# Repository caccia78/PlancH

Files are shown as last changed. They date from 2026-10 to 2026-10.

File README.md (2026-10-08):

# PlancH

**A desk button panel for Home Assistant.** Ten tactile buttons, a small OLED display, a touch
area and thirteen addressable RGB LEDs on a black PCB that sits on your desk, either on its own
rubber feet or on a 3D-printed stand. Powered by a Waveshare ESP32-S3-Zero running
[ESPHome](https://esphome.io), with native Home Assistant integration.

**📖 Documentation: [caccia78.github.io/PlancH](https://caccia78.github.io/PlancH/)**

https://github.com/user-attachments/assets/e7710835-a2c8-45fb-a4f4-b32c819555f0

*The video is also in [`media/`](media/) (MP4 and WebM).*

> **Status: Rev. 1, prototypes on order.** The design is complete and passes ERC/DRC, but the
> first boards have not been assembled and tested yet. Build one if you like to tinker, and
> expect changes.

## Features

- **10 tactile buttons**: a directional pad (up, down, left, right, OK), Back, and four scene buttons.
- **0.96" OLED display** (SSD1306, 128 × 64, white) for menus and feedback.
- **Capacitive touch area** on the top "ear" to wake the display.
- **13 addressable RGB LEDs** (SK6812): 3 status LEDs, 4 scene LEDs shining through milled
  windows in the PCB, and 6 backlight LEDs that light up the desk underneath.
- **Waveshare ESP32-S3-Zero** module, powered and programmed over USB-C.
- **Hand-solderable**: no parts with contacts under the body, passives 0805 or larger.
- **ESPHome firmware** with native Home Assistant API.
- **Accessories**: a 3D-printed desk stand, with more to come.

| Front | Back |
| --- | --- |
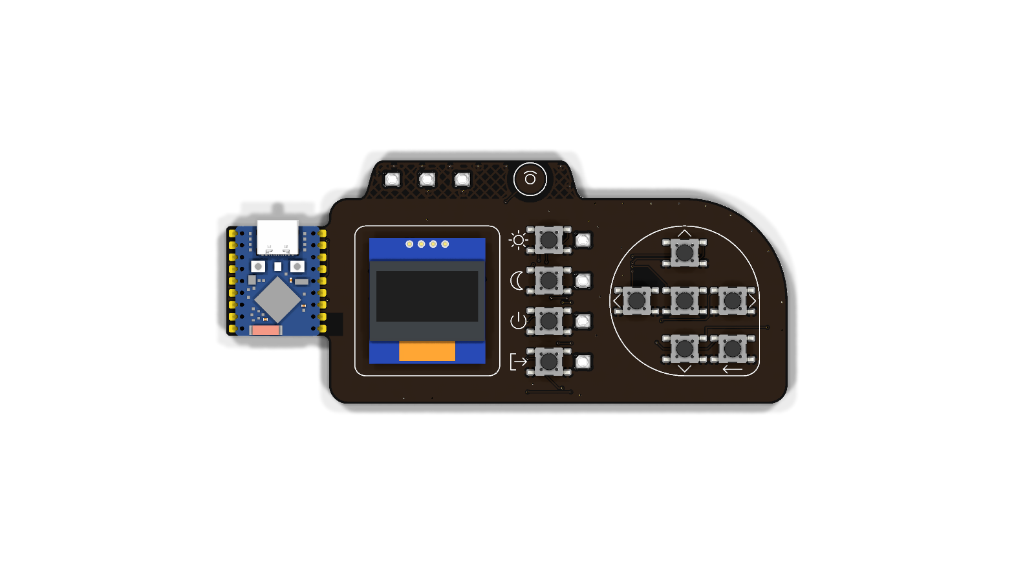
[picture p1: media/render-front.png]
Front render
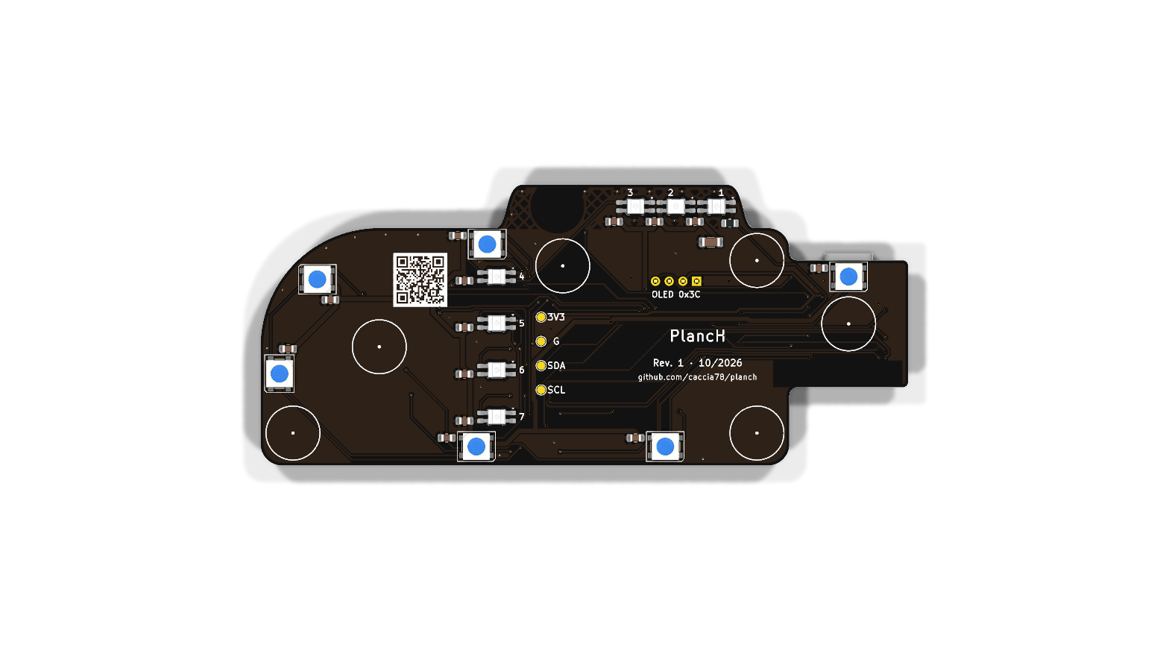
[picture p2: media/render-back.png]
Back render
|  |  |

## Build your own

1. **Order the PCB.** Upload `production/gerber/` (or the Gerber ZIP attached to the
   [latest release](../../releases/latest)) to JLCPCB, PCBWay or any other maker.
   Reference settings: 2 layers, 2.0 mm FR4 (1.6 mm works too), matte black solder mask,
   white silkscreen, ENIG finish.
2. **Get the components.** The bill of materials is in
   [`production/planch-bom.csv`](production/planch-bom.csv), with manufacturer part numbers.
3. **Solder.** Open [`production/planch-ibom.html`](production/planch-ibom.html) in a browser:
   the interactive BOM highlights every part on the board. Suggested order: passives and LEDs
   on the back, buttons, ESP32 module, OLED last.
4. **Flash the firmware.** Run `esphome run firmware/planch.yaml` and set the Wi-Fi after
   flashing. Then install the Home Assistant package `homeassistant/planch.yaml` and put the
   label **PlancH** on the devices to control: the panel finds them by itself, by room.
5. **Print a stand** (optional): the [desk stand](mechanical/desk-stand/README.md) or the
   magnetic [wall mount](mechanical/wall-mount/README.md), with ready-to-print 3MF and STL files.

The [project website](https://caccia78.github.io/PlancH/) has the full documentation:
[components with shop links](https://caccia78.github.io/PlancH/build/components/),
[PCB ordering](https://caccia78.github.io/PlancH/build/ordering/), a step-by-step
[assembly guide](https://caccia78.github.io/PlancH/build/assembly/),
[firmware](https://caccia78.github.io/PlancH/firmware/) and
[Home Assistant](https://caccia78.github.io/PlancH/home-assistant/) setup.

## Repository layout

```
hardware/      KiCad 10 project: schematic, PCB, custom symbols, footprints and 3D models
production/    Gerber and drill files, BOM, pick-and-place, interactive BOM, schematic PDF, STEP
mechanical/    3D-printable accessories (build123d sources, STL, 3MF, STEP)
firmware/      ESPHome: planch.yaml (board), planch-bringup.yaml (assembly test), planch-test.yaml (test bench)
homeassistant/ Home Assistant package (menu from labels and areas) and test bench dashboard
media/         renders and video
```

## License

PlancH is open source hardware.

- **Hardware** (KiCad sources, production files, 3D-printed accessories):
  [CERN-OHL-S v2](LICENSES/CERN-OHL-S-2.0.txt)
- **Firmware and scripts**: [MIT](LICENSES/MIT.txt)
- **Documentation, renders and video**: [CC BY-SA 4.0](LICENSES/CC-BY-SA-4.0.txt)

See [LICENSE.md](LICENSE.md) for details. The source location printed on the back of the board
is `github.com/caccia78/planch`.

© 2026 Vincenzo Cacciatore

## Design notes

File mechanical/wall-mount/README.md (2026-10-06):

# Wall mount

Hangs PlancH on a wall or any flat vertical surface. A ring bracket is glued behind the board in
place of the rubber feet, a base is stuck to the wall with removable adhesive strips, and six
5 × 3 mm magnets plus two centring cones hold them together. Both parts follow the board outline
9.5 mm in, so the backlight LEDs shine on the wall around them.

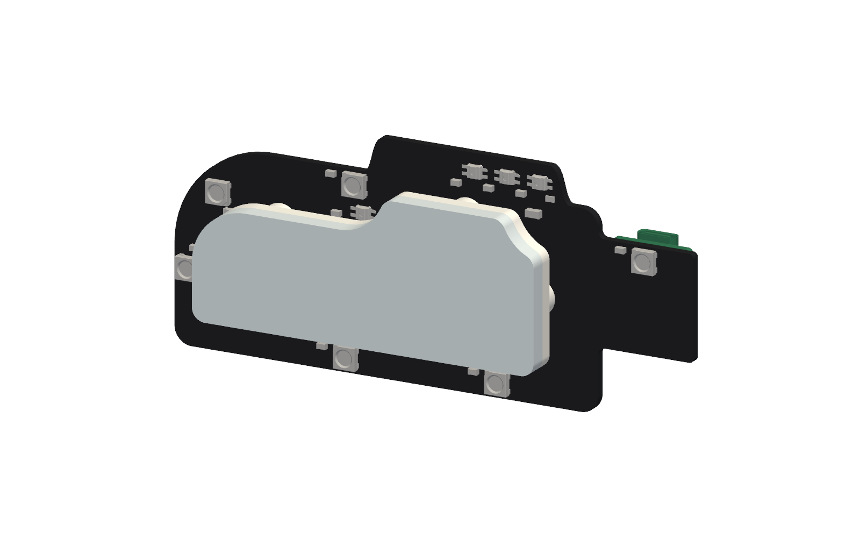
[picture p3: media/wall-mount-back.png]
Wall mount behind the board


Full instructions (parts list, magnet polarity, assembly) on the
[project website](https://caccia78.github.io/PlancH/accessories/wall-mount/).

## Files

| File | Use |
| --- | --- |
| `planch-wall-bracket.3mf`, `planch-wall-base.3mf` | Ready for Bambu Studio / PrusaSlicer, already oriented |
| `planch-wall-bracket.stl`, `planch-wall-base.stl` | Any slicer |
| `planch-wall-bracket.step`, `planch-wall-base.step` | CAD |
| `parete.py` | Parametric source ([build123d](https://github.com/gumyr/build123d) and shapely) |

## Printing

- PLA, both parts with the wall side on the bed, no supports.
- White or light PLA for the base: it sits in the backlight.

## Changing it

```bash
uv run --no-project --python 3.12 --with build123d --with shapely python parete.py \
    --board ../../production/planch.step --out .
```

The script writes `parete-staffa` (bracket) and `parete-base` (base) files ("parete" is Italian
for "wall", "staffa" for "bracket") and checks that the pads avoid the components on the back
and that no part covers the backlight LEDs.

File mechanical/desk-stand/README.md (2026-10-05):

# Desk stand

A 3D-printed stand that holds PlancH at 20° on the desk. The board keeps its rubber feet and
simply drops into a frame that follows its outline; slots in the frame let the backlight LEDs
shine out.

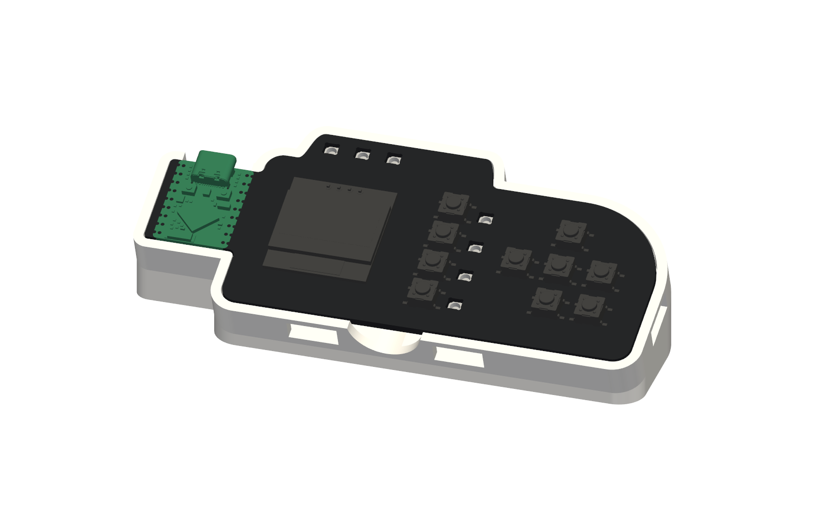
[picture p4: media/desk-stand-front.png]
Desk stand with PlancH


## Files

| File | Use |
| --- | --- |
| `planch-desk-stand.3mf` | Ready for Bambu Studio / PrusaSlicer, already oriented |
| `planch-desk-stand.stl` | Any slicer |
| `planch-desk-stand.step` | CAD |
| `leggio.py` | Parametric source ([build123d](https://github.com/gumyr/build123d)) |

## Printing

- PLA, printed on its base, no supports. Tested settings: Bambu Lab A1, 0.2 mm layers, 15% infill.
- White or light PLA works best: the inside of the frame reflects the backlight through the slots.
- Four 10 mm rubber bumpers go in the recesses underneath.

## Fit

The frame is sized for the board with its 5 mm feet and a 0.3 mm gap on every side. If your
printer runs tight or your feet are taller, regenerate the model:

```bash
uv run --no-project --python 3.12 --with build123d python leggio.py \
    --board ../../production/planch.step --out . --feet 6 --pcb 1.6
```

`--pcb` is the board thickness (2.0 mm by default, 1.6 mm for thinner boards), `--feet` the
height of the rubber feet. The script writes `leggio.*` files ("leggio" is Italian for
"stand").

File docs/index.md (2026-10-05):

---
hide:
  - navigation
  - toc
---

# PlancH

**A desk button panel for Home Assistant.** Ten tactile buttons, a small OLED display, a touch
area and thirteen addressable RGB LEDs on a black PCB that sits on your desk, on its own rubber
feet or on a 3D-printed stand. Powered by a Waveshare ESP32-S3-Zero running
[ESPHome](https://esphome.io), with native Home Assistant integration.

<video class="hero-video" controls muted playsinline preload="metadata" poster="media/planch-video-poster.png">
  <source src="media/planch-video.webm" type="video/webm">
  <source src="media/planch-video.mp4" type="video/mp4">
</video>

!!! warning "Rev. 1: prototypes on order"
    The design is complete and passes ERC and DRC, but the first boards have not been
    assembled and tested yet. Build one if you like to tinker, and expect changes.

<div class="grid cards" markdown>

-   :material-gesture-tap-button: **10 buttons**

    ---

    Directional pad with OK, Back, and four scene buttons for your favourite routines.

-   :material-monitor: **OLED display**

    ---

    0.96" SSD1306, 128 × 64 white pixels for menus and feedback, woken by a touch on the top
    "ear".

-   :material-led-strip-variant: **13 RGB LEDs**

    ---

    3 status LEDs, 4 scene LEDs shining through windows milled in the PCB, and 6 backlight
    LEDs that light up the desk.

-   :material-home-assistant: **ESPHome inside**

    ---

    Waveshare ESP32-S3-Zero over USB-C, native Home Assistant API, no cloud.

-   :material-soldering-iron: **Hand-solderable**

    ---

    No parts with contacts under the body, passives 0805 or larger. About 2–3 hours for the
    first board.

-   :material-printer-3d-nozzle: **Accessories**

    ---

    A 3D-printed desk stand, with more mounts to come.

</div>

| Front | Back |
| --- | --- |
| Front of the board | Back of the board |

## Build your own

<div class="grid cards" markdown>

-   :material-format-list-checks: **[Components](build/components.md)**

    Bill of materials with shop links.

-   :material-chip: **[Ordering the PCB](build/ordering.md)**

    Gerber files and fab settings.

-   :material-soldering-iron: **[Assembly](build/assembly.md)**

    Step-by-step soldering guide with a test at every stage.

-   :material-download: **[Firmware](firmware/index.md)**

    Flash ESPHome and connect to Home Assistant.

</div>

All design files (KiCad sources, Gerbers, 3D models, firmware) are in the
[GitHub repository](https://github.com/caccia78/PlancH). PlancH is
[open source hardware](about/license.md).

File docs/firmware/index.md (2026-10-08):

# Firmware

PlancH runs [ESPHome](https://esphome.io). The devices to control are not written in the
firmware: you choose them in Home Assistant with a label, and PlancH builds its menu by itself,
by room and by type. See [Home Assistant](../home-assistant/index.md) for the setup.

| File | Use |
| --- | --- |
| [`firmware/planch.yaml`](https://github.com/caccia78/PlancH/blob/main/firmware/planch.yaml) | **The firmware**: menu on the display, keys, LEDs |
| [`firmware/planch/`](https://github.com/caccia78/PlancH/tree/main/firmware/planch) | Shared logic (`core.yaml`, `menu.h`): keep it next to `planch.yaml` |
| [`firmware/planch-bringup.yaml`](https://github.com/caccia78/PlancH/blob/main/firmware/planch-bringup.yaml) | Assembly test: buttons and LED groups on a web page, see the [assembly guide](../build/assembly.md) |
| [`firmware/planch-test.yaml`](https://github.com/caccia78/PlancH/blob/main/firmware/planch-test.yaml) | Test bench on any ESP32 board, without the PlancH hardware: see [Try it without the hardware](test-bench.md) |

## Install from the browser

The quickest way, with nothing to install: the firmware is built from this repository and
written by the browser (Chrome or Edge on a computer).

<script type="module" src="https://unpkg.com/esp-web-tools@10.4.0/dist/web/install-button.js?module"></script>

<p>
  <esp-web-install-button manifest="/PlancH/firmware/install/manifest.json">
    <span slot="unsupported">This browser cannot talk to USB devices: open the page in Chrome or Edge on a computer.</span>
    <span slot="not-allowed">The installer needs a secure (https) page.</span>
  </esp-web-install-button>
</p>

1. Connect the board with a USB-C **data** cable and press **Connect** above.
2. Choose the serial port of the board. If it does not appear, hold the **BOOT** button of the
   ESP32-S3-Zero while plugging in the cable, then try again.
3. Choose **Install PlancH**. Erasing the board is fine for a first installation.
4. At the end choose **Configure Wi-Fi**, pick your network and type its password: it stays on
   the board, not in any file.
5. Add the board to Home Assistant as described in [Home Assistant](../home-assistant/index.md).

This button installs PlancH on its ESP32-S3-Zero. To try the menu on a spare ESP32 board before
building PlancH, see [Try it without the hardware](test-bench.md).

## Flash with ESPHome

You need [ESPHome](https://esphome.io/guides/installing_esphome) on your computer
(`pip install esphome`, or `uvx esphome` with [uv](https://docs.astral.sh/uv/)), or the ESPHome
Device Builder add-on in Home Assistant.

1. Download the repository, or just the `firmware/` folder. With the Device Builder, copy
   `planch.yaml` and the `planch/` folder into the `esphome` folder of Home Assistant (next to
   `configuration.yaml`).
2. Connect the board with a USB-C **data** cable.
3. Run:

    ```bash
    esphome run firmware/planch.yaml
    ```

    The first time, choose the USB serial port. If the board is not detected, hold the **BOOT**
    button on the ESP32-S3-Zero while plugging in the cable.

4. **Wi-Fi.** The firmware has no Wi-Fi password in it: set it after flashing.
    - Open [web.esphome.io](https://web.esphome.io) in Chrome or Edge, press **Connect**, pick
      the board and choose **Configure Wi-Fi**; or
    - join the **PlancH** Wi-Fi network that the board opens while it has no network, and pick
      your network on the page that appears (or open `192.168.4.1`).
5. Later updates go over Wi-Fi (OTA): run the same command and pick the network address.

Then add the board to Home Assistant and enable its actions, as described in
[Home Assistant](../home-assistant/index.md).

## Keys and display

The display shows rooms → types in the room (skipped if there is only one) → devices →
the controls of one device.

| Key | In the lists | On a device |
| --- | --- | --- |
| Up, Down | Move | Light: move through its rows, and past the last row on to the next light. Switch, thermostat: previous / next. Cover: open / close |
| OK | Enter | Light, switch, thermostat: on / off. Cover: stop |
| Left, Right | Back / enter | Light: change the selected row. Switch: off / on. Thermostat: −/+ 0.5 °C |
| Back | Go back | Go back to the list |
| Scene 1–4 | Run the scene, script or automation assigned in Home Assistant | Same |
| Touch | Wake the display | Wake the display |

The screen of a light shows only the rows that the light supports:

```
Strip
> Brightness      70%
  Colour          Red
  White         2700K
  Effect       Candle
```

- **Brightness**: ±10% (a light that can only switch on and off has a **State** row instead).
- **Colour**: previous / next colour of the palette defined in the
  [Home Assistant package](../home-assistant/index.md#colours); the row shows the palette colour
  closest to the current one.
- **White**: warmer / cooler in steps of 500 K, within the range of the light.
- **Effect**: previous / next effect of the light (WLED and many others), picked by Home
  Assistant from the light's own list.

The display switches off after 30 seconds without keys; the first key only wakes it up. The
scene keys work with the display off too.

## LEDs

| LED | Meaning |
| --- | --- |
| D1 (ear, left) | Off when everything is fine. Red: no connection to Home Assistant. Amber: menu missing, empty or over the limits. Short red flash: a command failed |
| D2, D3 (ear) | Free: two RGB lights in Home Assistant, **Status LED 2** and **Status LED 3**, for your automations |
| D4–D7 (scene keys) | On with the display, and for 5 seconds after a scene key. Full on the **active scene**, dim on the other assigned keys. After a press: green if Home Assistant confirms, red on error |
| D8–D13 (backlight) | The RGB light **Backlight** in Home Assistant |

LED brightness is limited to 40% in the firmware to keep the USB current low.

## What the firmware exposes

| Entity | Type | Notes |
| --- | --- | --- |
| Up, Down, Left, Right, OK, Back, Scene 1 – Scene 4 | Binary sensor | `on` while pressed: you can use them in automations too |
| Panel | Text | Name of the panel, picks its devices: see [More than one PlancH](../home-assistant/index.md#more-than-one-planch) |
| Touch | Binary sensor | Capacitive area on the ear, calibrate the threshold |
| Status LED 2, Status LED 3 | Light (RGB) | D2 and D3 on the ear |
| Backlight | Light (RGB) | D8–D13, towards the desk (or the wall) |

## Calibrating the touch area

The touch threshold depends on your board and on the stand. With `setup_mode: true` (the
default in `planch.yaml`) the ESPHome log prints the raw touch value:

1. Read the value at rest and with a finger on the ear.
2. Set `threshold` about halfway between the two.
3. Set `setup_mode: false` and flash again.

## Test bench without the hardware

The same menu runs on any ESP32 board with nothing connected, driven from a Home Assistant card
that draws PlancH: see [Try it without the hardware](test-bench.md).

## Pinout

| GPIO | Function | GPIO | Function |
| --- | --- | --- | --- |
| 1 | Up | 9 | Scene 1 |
| 2 | Down | 10 | LED data (via 330 Ω) |
| 3 | Left (strapping pin, input only) | 11 | I²C SDA |
| 4 | Right | 12 | I²C SCL |
| 5 | OK | 13 | Touch |
| 6 | Scene 4 | 44 (RX) | Back |
| 7 | Scene 3 | 43 (TX) | not used (boot log) |
| 8 | Scene 2 | 21 | RGB LED on the module |

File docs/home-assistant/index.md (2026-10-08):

# Home Assistant

PlancH talks to Home Assistant through the native ESPHome API: no MQTT broker, no cloud.
You choose what it controls with **labels**: PlancH finds the devices by itself and groups them
by room (area) and type, so adding a lamp to the panel takes one click and no new firmware.

## 1 · Install the PlancH package

The package
[`homeassistant/planch.yaml`](https://github.com/caccia78/PlancH/blob/main/homeassistant/planch.yaml)
creates the sensor `sensor.planch_menu`, which collects the labelled devices with their state
and sends them to the panel.

1. In the Home Assistant configuration folder (the one with `configuration.yaml`) create a
   folder `packages` and copy `planch.yaml` into it.
2. If `configuration.yaml` does not load packages yet, add at the top level:

    ```yaml
    homeassistant:
      packages: !include_dir_named packages
    ```

3. **Developer tools → YAML → Check configuration**, then restart Home Assistant.
4. In **Developer tools → States** you find `sensor.planch_menu`: its state is the number of
   labelled devices (0 for now).

## 2 · Add the board

1. [Flash the firmware](../firmware/index.md) and let the board join your Wi-Fi.
2. Home Assistant discovers it: open **Settings → Devices & services**, find **PlancH** under
   *Discovered* and click **Configure**. If it is not discovered, click **Add integration →
   ESPHome** and enter the board's IP address (or `planch.local`).
3. On the ESPHome integration, open the **PlancH** device options (**Configure**) and enable
   **Allow the device to perform Home Assistant actions**. Without it the menu shows up but
   the keys do nothing.

## 3 · Choose the devices

Create the label **PlancH** (**Settings → Areas, labels & zones → Labels**) and put it on the
lights, switches (smart plugs), covers and thermostats (climate) you want on the panel.

- Put it on the **entity**, to choose exactly what appears; or on the **device**, to take all
  its lights, switches, covers and thermostats.
- A lamp on a smart plug is often a `switch`: it appears under **Switches**. To have it under
  **Lights**, turn it into a light with the Home Assistant helper *Change device type of a
  switch* and label the new light instead.
- The room is the area of the entity, or of its device. Without an area the device goes under
  **Other**.
- The name shown is the entity name without the room in front ("Living room Lamp" →
  "Lamp"), cut to 16 characters.

The menu updates by itself: states live, and labels or areas within a couple of seconds (the
package includes a small automation, **PlancH: refresh the menu when labels or areas change**,
for that).

!!! warning "Limits"
    A panel shows at most **8 rooms**, **8 devices per room** and **32 devices** in total:
    more would not fit in the ESP32 memory nor on the 0.96" display. Beyond the limits the list
    is cut, the LED D1 turns amber and the room list reads "Rooms (limit!)".

### More than one PlancH

Each panel can show its own devices besides the shared ones:

1. Give the panel a name: on its device page in Home Assistant, under **Configuration**, type
   it in the **Panel** field (for example *Studio*). No new firmware needed.
2. Create the label **PlancH Studio** and put it on the devices for that panel only.

The panel named Studio shows the devices with **PlancH** and with **PlancH Studio**; a device
can have several labels to appear on more than one panel. A panel without a name, or with a
name that has no label, shows the **PlancH** devices. Names are not case sensitive, and up to
6 named panels are supported.

## 4 · Assign the scene keys

Create the labels **PlancH S1**, **PlancH S2**, **PlancH S3** and **PlancH S4** and put each
one on the scene, script or automation for that key (one entity per label): a scene is turned
on, a script is run, an automation is triggered. A key without a label does nothing.

With more panels, **PlancH Studio S1** … **PlancH Studio S4** set the keys of the panel Studio
only, and win over the shared ones.

The LED next to each key shows the **active scene**: the one activated most recently among the
four, also when you activate it from Home Assistant or from an automation (a script also while
it runs). When you press a key, its LED turns green if Home Assistant confirms, red on error.

## Colours

On a colour light the panel steps through a **palette**, defined at the top of the `palette`
attribute in `planch.yaml`. Edit it as you like: name (up to 10 characters), hue (0–360) and
saturation (0–100).

{% raw %}
```yaml
{%- set palette = [
  ['White', 0, 0], ['Warm white', 35, 45], ['Orange', 30, 100], ['Red', 0, 100],
  ['Pink', 330, 65], ['Violet', 275, 80], ['Blue', 225, 100], ['Cyan', 185, 90],
  ['Green', 120, 90], ['Yellow', 55, 90]] %}
```
{% endraw %}

The favourite colours that Home Assistant shows in the light dialog are stored where templates
cannot read them, so the panel uses this list instead. Lights with a white temperature get a
**White** row, lights with effects (WLED and many others) an **Effect** row: see the
[Firmware](../firmware/index.md#keys-and-display) page.

## Example: a status LED for the front door

D2 and D3 on the ear are free for your automations:

```yaml
automation:
  - alias: "PlancH: D2 red while the front door is open"
    triggers:
      - trigger: state
        entity_id: binary_sensor.front_door
    actions:
      - if:
          - condition: state
            entity_id: binary_sensor.front_door
            state: "on"
        then:
          - action: light.turn_on
            target:
              entity_id: light.planch_status_led_2
            data:
              rgb_color: [255, 0, 0]
              brightness_pct: 40
        else:
          - action: light.turn_off
            target:
              entity_id: light.planch_status_led_2
```

## Example: dim the backlight at night

```yaml
automation:
  - alias: "PlancH: warm, dim backlight after sunset"
    triggers:
      - trigger: sun
        event: sunset
    actions:
      - action: light.turn_on
        target:
          entity_id: light.planch_backlight
        data:
          rgb_color: [255, 180, 110]
          brightness_pct: 20
```

Entity IDs depend on the device name: check them on the device page and adjust the examples.

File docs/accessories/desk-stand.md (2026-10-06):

# Desk stand

A 3D-printed stand that holds PlancH at 20° on the desk. The board keeps its rubber feet and
simply drops into a frame that follows its outline: no screws, no glue, and it lifts out with
a finger through the notch at the front. Slots in the frame let the backlight LEDs shine out
onto the desk.

<div class="grid" markdown>
<figure markdown="span">
  Desk stand with PlancH, front
  <figcaption>The board in the stand.</figcaption>
</figure>
<figure markdown="span">
  Desk stand, side view
  <figcaption>Side view: 20° tilt.</figcaption>
</figure>
</div>

## 3D View

Inspect the stand design in 3D, on its own or with the board in place. With the board shown
you can also switch on the LEDs, by group as in the firmware: the backlight shining on the desk
is suggested by the glowing light slots.

--8<-- "model-viewer.html"

<div style="margin: 2rem 0 0.5rem; border: 1px solid var(--md-border-color); border-radius: 8px; overflow: hidden;">
  <model-viewer 
    id="leggio-3d"
    src="/PlancH/assets/leggio-viewer.glb"
    alt="PlancH desk stand 3D model"
    auto-rotate
    camera-controls
    style="width: 100%; height: 500px; display: block;">
    <!-- HDR rendering: only the LEDs, with emissive strength above 1, pass the threshold -->
    <effect-composer render-mode="quality">
      <bloom-effect strength="0.8" threshold="3" radius="0.6"></bloom-effect>
    </effect-composer>
  </model-viewer>
</div>

<p>
  <button type="button" class="md-button" id="leggio-scheda" aria-pressed="false">Show the board</button>
  <button type="button" class="md-button" data-viewer-background="leggio-3d" aria-pressed="false">Dark background</button>
</p>
<p id="leggio-led-controlli" hidden>
  LEDs:
  <button type="button" class="md-button" data-led="led_stato" aria-pressed="false">Status</button>
  <button type="button" class="md-button" data-led="led_scene" aria-pressed="false">Scenes</button>
  <button type="button" class="md-button" data-led="led_retro" aria-pressed="false">Backlight</button>
  <label>Colour <input type="color" value="#ff7043"></label>
</p>

<script>
  planchLeds("leggio-3d", "leggio-led-controlli");
  planchBoardToggle("leggio-3d", "leggio-scheda", {
    parts: "/PlancH/assets/leggio-viewer.glb",
    board: "/PlancH/assets/leggio-assieme-viewer.glb",
  }, "leggio-led-controlli");
</script>

## Files

| File | Use |
| --- | --- |
| [`planch-desk-stand.3mf`](https://github.com/caccia78/PlancH/raw/main/mechanical/desk-stand/planch-desk-stand.3mf) | Ready for Bambu Studio / PrusaSlicer, already oriented |
| [`planch-desk-stand.stl`](https://github.com/caccia78/PlancH/blob/main/mechanical/desk-stand/planch-desk-stand.stl) | Any slicer (GitHub shows it in 3D) |
| [`planch-desk-stand.step`](https://github.com/caccia78/PlancH/raw/main/mechanical/desk-stand/planch-desk-stand.step) | CAD |
| [`leggio.py`](https://github.com/caccia78/PlancH/blob/main/mechanical/desk-stand/leggio.py) | Parametric source (build123d) |

## Printing

- **Material**: PLA, about 35 g with 15% infill.
- **Orientation**: on its base, as in the 3MF. No supports needed.
- **Colour**: white or light PLA works best: the inside of the frame reflects the backlight
  through the slots.
- **Tested on**: Bambu Lab A1, 0.4 mm nozzle, 0.2 mm layers.
- **Bumpers**: four Ø 10 mm rubber bumpers go in the recesses underneath, so the stand does not
  slide when you press the buttons.

## Design

| Parameter | Value |
| --- | --- |
| Tilt | 20° |
| Rubber feet height | 5 mm |
| Board thickness | 2.0 mm |
| Gap between board and frame | 0.3 mm per side |
| Walls / floor | 2.4 / 2.0 mm |
| Wall top | 0.5 mm below the top face of the board |
| Overall size | about 125 × 57 × 31 mm |

- The frame outline is read from the board STEP file, so it always follows the real PCB edge.
- Five light slots face the backlight LEDs D8–D12; D13 shines out of the USB-C opening.
- The USB-C opening leaves room for the plug and its overmould; the cable leaves from the top,
  behind the stand.

## Adapting it

If your board is 1.6 mm thick, your feet are taller or your printer runs tight, regenerate the
model with [uv](https://docs.astral.sh/uv/) from the repository root:

```bash
cd mechanical/desk-stand
uv run --no-project --python 3.12 --with build123d python leggio.py \
    --board ../../production/planch.step --out . --pcb 1.6 --feet 5 --tilt 20
```

The script writes `leggio.stl`, `leggio.3mf` and `leggio.step` ("leggio" is Italian for
"stand").

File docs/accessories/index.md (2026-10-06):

# Accessories

3D-printable accessories for PlancH. Each one comes with ready-to-print files and a parametric
[build123d](https://github.com/gumyr/build123d) source in
[`mechanical/`](https://github.com/caccia78/PlancH/tree/main/mechanical), so you can adapt it
to your printer, your board thickness or your desk.

<div class="grid cards" markdown>

-   :material-desk: **[Desk stand](desk-stand.md)**

    ---

    Holds the board at 20° on the desk, with light slots for the backlight.

-   :material-wall: **[Wall mount](wall-mount.md)**

    ---

    Hangs the board on a wall or any flat vertical surface, held by magnets; the backlight
    glows on the wall around it.

-   :material-monitor: **Monitor and keyboard mounts** *(planned)*

    ---

    Clip-on holders for the monitor bezel or next to the keyboard, reusing the magnetic
    bracket of the wall mount.

</div>

Ideas for other mounts are welcome in the
[GitHub issues](https://github.com/caccia78/PlancH/issues).

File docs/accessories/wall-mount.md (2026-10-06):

# Wall mount

Hangs PlancH on a wall, a cupboard door or any flat vertical surface. Two printed parts held
together by magnets: a ring **bracket** glued behind the board in place of the rubber feet, and
a **base** stuck to the wall with removable adhesive strips. The board snaps on and pulls off
by hand, and the backlight LEDs shine on the wall around it.

<div class="grid" markdown>
<figure markdown="span">
  Wall mount behind the board
  <figcaption>From behind: the base (front) on the bracket.</figcaption>
</figure>
<figure markdown="span">
  Wall mount parts
  <figcaption>The bracket with its magnet and centring seats, and the base.</figcaption>
</figure>
</div>

## 3D View

Inspect the two parts on the wall, or show the board hanging on them. With the board shown you
can also switch on the LEDs: the backlight lights up the wall around the board.

--8<-- "model-viewer.html"

<div style="margin: 2rem 0 0.5rem; border: 1px solid var(--md-border-color); border-radius: 8px; overflow: hidden;">
  <model-viewer 
    id="parete-3d"
    src="/PlancH/assets/wall-mount-viewer.glb"
    alt="PlancH wall mount 3D model"
    camera-orbit="25deg 80deg auto"
    camera-controls
    style="width: 100%; height: 500px; display: block;">
    <!-- HDR rendering: only the LEDs, with emissive strength above 1, pass the threshold -->
    <effect-composer render-mode="quality">
      <bloom-effect strength="0.8" threshold="3" radius="0.6"></bloom-effect>
    </effect-composer>
  </model-viewer>
</div>

<p>
  <button type="button" class="md-button" id="parete-scheda" aria-pressed="false">Show the board</button>
  <button type="button" class="md-button" data-viewer-background="parete-3d" aria-pressed="false">Dark background</button>
</p>
<p id="parete-led-controlli" hidden>
  LEDs:
  <button type="button" class="md-button" data-led="led_stato" aria-pressed="false">Status</button>
  <button type="button" class="md-button" data-led="led_scene" aria-pressed="false">Scenes</button>
  <button type="button" class="md-button" data-led="led_retro" aria-pressed="false">Backlight</button>
  <label>Colour <input type="color" value="#ff7043"></label>
</p>

<script>
  planchLeds("parete-3d", "parete-led-controlli");
  planchBoardToggle("parete-3d", "parete-scheda", {
    parts: "/PlancH/assets/wall-mount-viewer.glb",
    board: "/PlancH/assets/wall-mount-assieme-viewer.glb",
  }, "parete-led-controlli");
</script>

## What you need

| Item | Quantity | Notes |
| --- | --- | --- |
| Printed bracket and base | 1 + 1 | PLA, see below |
| Neodymium disc magnets Ø 5 × 3 mm | 12 | N35 or stronger: six in the bracket, six in the base |
| Double-sided VHB dots Ø 8 mm, 1 mm thick | 6 | Clear acrylic foam, for example 3M 4910; sold pre-cut |
| Removable adhesive strips | 2 | 3M Command Small (about 44 × 16 mm) or similar |
| Cyanoacrylate glue | — | For the magnets |

## Files

| File | Use |
| --- | --- |
| [`planch-wall-bracket.3mf`](https://github.com/caccia78/PlancH/raw/main/mechanical/wall-mount/planch-wall-bracket.3mf) | Bracket, ready for Bambu Studio / PrusaSlicer, already oriented |
| [`planch-wall-base.3mf`](https://github.com/caccia78/PlancH/raw/main/mechanical/wall-mount/planch-wall-base.3mf) | Base, ready for Bambu Studio / PrusaSlicer, already oriented |
| [`planch-wall-bracket.stl`](https://github.com/caccia78/PlancH/blob/main/mechanical/wall-mount/planch-wall-bracket.stl), [`planch-wall-base.stl`](https://github.com/caccia78/PlancH/blob/main/mechanical/wall-mount/planch-wall-base.stl) | Any slicer (GitHub shows them in 3D) |
| [`planch-wall-bracket.step`](https://github.com/caccia78/PlancH/raw/main/mechanical/wall-mount/planch-wall-bracket.step), [`planch-wall-base.step`](https://github.com/caccia78/PlancH/raw/main/mechanical/wall-mount/planch-wall-base.step) | CAD |
| [`parete.py`](https://github.com/caccia78/PlancH/blob/main/mechanical/wall-mount/parete.py) | Parametric source (build123d) |

## Printing

- **Material**: PLA, about 15 g for both parts.
- **Orientation**: the face that goes towards the wall on the bed, as in the 3MF files. No
  supports needed.
- **Colour**: white or light PLA for the base: it sits in the backlight and reflects it.

## Assembly

1. **Magnets in the base.** Glue the six magnets in the seats of the base with a drop of
   cyanoacrylate, all with the **same pole facing out**: stack them on each other first and
   take them one by one from the same end of the stack.
2. **Magnets in the bracket.** Put a second magnet on top of each magnet of the base: it turns
   itself the right way. Put a small drop of glue on top of each, lower the bracket onto them
   (the two cones of the base guide it) and let the glue set. When you pull the bracket off,
   its magnets come with it, with the right polarity.
3. **Bracket on the board.** Remove the rubber feet and clean the back with isopropyl alcohol.
   Stick a VHB dot on each of the six round pads of the bracket, then press the bracket on the
   back of the board, centred on the main body: it follows the outline at the same distance
   all around, and the module tab stays free. Hold it pressed for 30 seconds.
4. **Base on the wall.** Stick the two adhesive strips horizontally on the flat back of the
   base, with the pull tabs facing down. Press the base on a clean wall for 30 seconds, using a
   spirit level. Leave **45 mm free above the board**: the USB-C plug comes out of the top edge
   of the module tab.
5. **Board on the base.** Bring the board close: the cones centre it and the magnets pull it in.

To take it down, pull the board straight off the wall; then pull the tabs of the strips
slowly down along the wall. To put the board back on the [desk stand](desk-stand.md), cut the
VHB dots with fishing line or dental floss (a little warmth from a hair dryer helps) and stick
new rubber feet.

## Design

| Parameter | Value |
| --- | --- |
| Shape | Board outline, 9.5 mm in from the edge of the main body |
| Bracket | 8 mm wide ring, 3 mm thick, six Ø 8 mm pads 2.4 mm high |
| Base | Same shape, solid, 4 mm thick, flat back |
| Centring | Two cones Ø 5 → 3 mm, 2 mm high, with 0.2 mm clearance |
| Board to wall | 10.4 mm |
| Overall size | 79 × 33 mm |

- The pads sit where the back of the board has no components; the ring clears the parts on the
  back (up to 1.8 mm high) by 1.6 mm.
- All six backlight LEDs are outside the bracket and the base, so they light the wall.
- The script checks both conditions every time it builds the model.

## Adapting it

To change the clearances, the thickness or the distance from the edge, regenerate the model
with [uv](https://docs.astral.sh/uv/) from the repository root:

```bash
cd mechanical/wall-mount
uv run --no-project --python 3.12 --with build123d --with shapely python parete.py \
    --board ../../production/planch.step --out .
```

The script writes `parete-staffa` (bracket) and `parete-base` (base) as STL, 3MF and STEP
("parete" is Italian for "wall", "staffa" for "bracket").

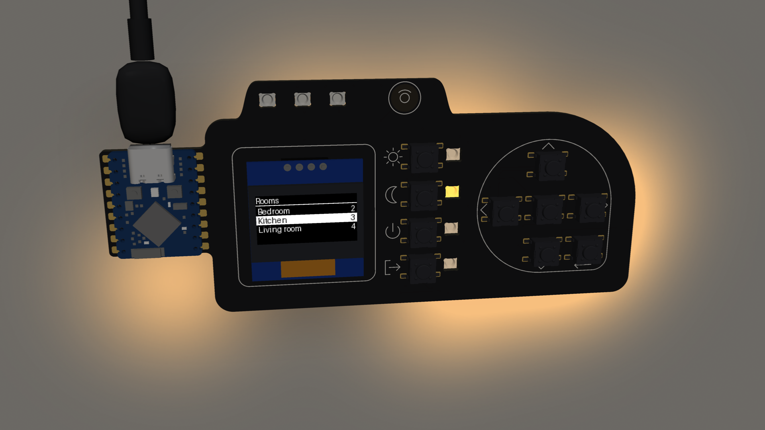
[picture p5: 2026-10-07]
media/planch-video-poster.png

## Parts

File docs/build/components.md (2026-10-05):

# Components

Everything needed for **one board**. The full BOM generated from the KiCad project, with
manufacturer part numbers, is in [`production/planch-bom.csv`](../production/planch-bom.csv).

{% set shops = {"digikey": "DigiKey", "aliexpress": "AliExpress", "amazon": "Amazon"} %}
{% macro link(l) -%}
{%- if l.shop == "amazon" -%}
[{{ shops[l.shop] }}](https://www.amazon.it/dp/{{ l.id }}{% if config.extra.amazon_tag %}?tag={{ config.extra.amazon_tag }}{% endif %}){: rel="sponsored nofollow" }
{%- elif l.shop == "aliexpress" -%}
[{{ shops[l.shop] }}](https://www.aliexpress.com/item/{{ l.id }}.html)
{%- else -%}
[{{ shops[l.shop] }}]({{ l.url }})
{%- endif %} {{ l.label }}
{%- endmacro %}

| Ref. | Part | Qty | Side | Package | Where to buy |
| --- | --- | :-: | --- | --- | --- |
{% for c in components -%}
| {{ c.ref }} | **{{ c.name }}**{% if c.mpn %}<br>`{{ c.mpn }}`{% endif %}{% if c.detail %}<br><small>{{ c.detail }}</small>{% endif %} | {{ c.qty }} | {{ c.side }} | {{ c.package }} | {% for l in c.links %}{{ link(l) }}{% if not loop.last %}<br>{% endif %}{% endfor %}{% if not c.links %}any, see notes{% endif %} |
{% endfor %}

## Notes

- **ESP32-S3-Zero**: buy the version **without** pre-soldered pin headers. The board is
  soldered by its castellated edges.
- **OLED**: most 0.96" I²C modules look alike, but the pin order is not standard. PlancH needs
  **GND, VIN, SCK, SDA** from left to right with the pins on top.
- **5050 LEDs**: buy the **RGB** version (3 channels), not RGBW. Mixing an RGBW LED into the
  chain shifts the colours of every LED after it.
- **Switches**: generic 6 × 6 × 4.3 mm SMD switches often have a slightly different pad
  layout from the C&K PTS645. Check the first one before soldering all ten.
- **Quantities**: SMD parts come in tapes of 10–100. Buying for several boards (or friends)
  costs almost the same as buying for one.

{% if config.extra.amazon_tag %}
!!! info "Affiliate links"
    Amazon links are affiliate links: as an Amazon Associate I earn from qualifying purchases,
    at no extra cost to you. It helps keep the project going.
{% endif %}

## Desk stand

The optional [desk stand](../accessories/desk-stand.md) needs 1 × PLA print (about 35 g) and
4 × rubber bumpers Ø 10 mm.

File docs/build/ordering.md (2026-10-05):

# Ordering the PCB

Download **`PlancH-v1.0-gerber.zip`** from the
[latest release](https://github.com/caccia78/PlancH/releases/latest) (or zip the files in
[`production/gerber/`](https://github.com/caccia78/PlancH/tree/main/production/gerber)) and
upload it to JLCPCB, PCBWay or any other PCB maker. You only need the **bare board**: every
part is soldered by hand.

## Recommended settings

| Option | Value |
| --- | --- |
| Layers | 2 |
| Size | 120 × 52 mm (detected from the Gerbers) |
| Thickness | **2.0 mm** (1.6 mm works too) |
| Copper | 1 oz |
| Solder mask | **Matte black**, both sides |
| Silkscreen | White |
| Surface finish | **ENIG** (lead-free HASL is fine for prototypes) |
| Vias | Tented |
| Internal cut-outs | Yes: 7 LED windows (3.4 × 3.0 mm) are in the outline file |
| Assembly | None |

## Notes

- **The front is meant to be seen.** Many fabs print their order number on the silkscreen:
  ask to remove it (JLCPCB: "Remove Mark") or to move it to the back.
- **The mask colour is an order option**, it is not in the Gerbers. Black matte looks best;
  any colour works electrically.
- **Board thickness** changes how deep the status LEDs sit in their windows: about 1.2 mm
  below the surface with 2.0 mm, about 0.8 mm with 1.6 mm. If you print the
  [desk stand](../accessories/desk-stand.md), generate it for the thickness you ordered.
- **Cost**: at the time of writing, five 1.6 mm boards in black with lead-free HASL cost a
  few euros at JLCPCB plus shipping. 2.0 mm and ENIG add a surcharge.
- The pick-and-place file [`production/planch-cpl.csv`](https://github.com/caccia78/PlancH/blob/main/production/planch-cpl.csv)
  is only useful if you choose an assembly service.

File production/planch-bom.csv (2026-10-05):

Reference | Value | Footprint | Manufacturer | MPN | LCSC | Qty
C1-C13 | 100n | Capacitor_SMD:C_0805_2012Metric_Pad1.18x1.45mm_HandSolder | Samsung | CL21B104KBCNNNC |  | 13
C14 | 47u | Capacitor_SMD:C_1206_3216Metric_Pad1.33x1.80mm_HandSolder | Samsung | CL31A476MPHNNNE |  | 1
D1-D7 | SK6812MINI-E | planch:LED_SK6812MINI-E_3.2x2.8mm_P1.5mm_ReverseMount_HandSolder | Opsco | SK6812MINI-E |  | 7
D8-D13 | SK6812 5050 RGB | LED_SMD:LED_SK6812_PLCC4_5.0x5.0mm_P3.2mm | Opsco | SKC6812RV |  | 6
R1 | 330 | Resistor_SMD:R_0805_2012Metric_Pad1.20x1.40mm_HandSolder | Yageo | RC0805FR-07330RL |  | 1
SW1-SW10 | PTS645SH43 | planch:SW_SPST_PTS645Sx43SMTR92_NoSilk | C&K | PTS645SH43SMTR92 LFS |  | 10
U1 | ESP32-S3-Zero | planch:Waveshare_ESP32-S3-Zero_Castellated | Waveshare | ESP32-S3-Zero |  | 1
U2 | OLED 0.96in SSD1306 | planch:OLED_SSD1306_0.96in_I2C_24.8x26.9mm |  | SSD1306 0.96in I2C module |  | 1

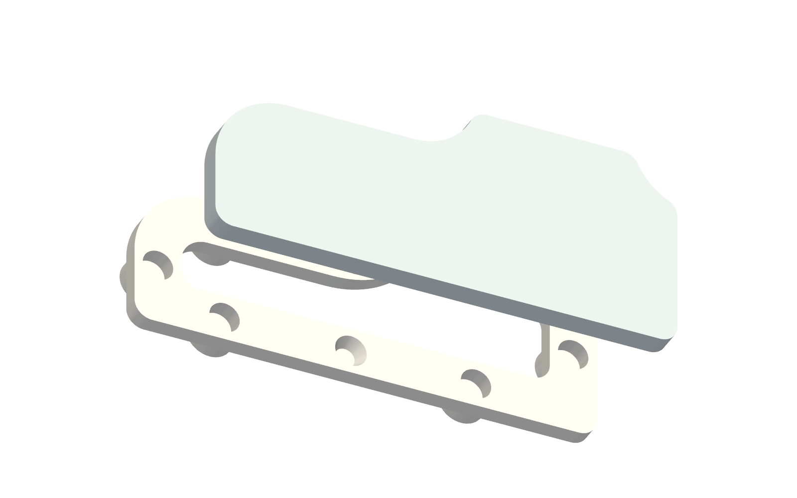
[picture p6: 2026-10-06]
media/wall-mount-parts.png

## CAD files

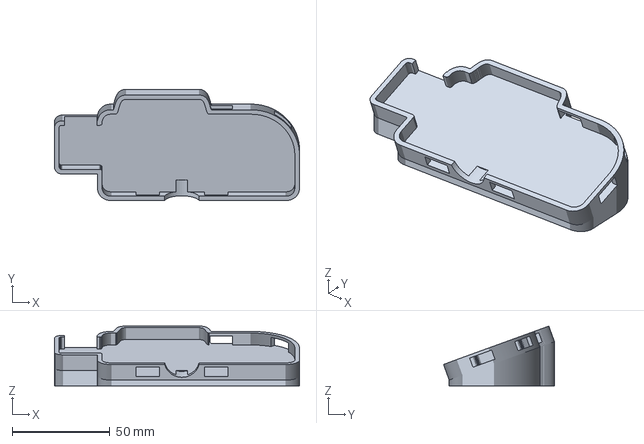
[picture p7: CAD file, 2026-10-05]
mechanical/desk-stand/planch-desk-stand.step
125.4 x 56.8 x 30.6 mm

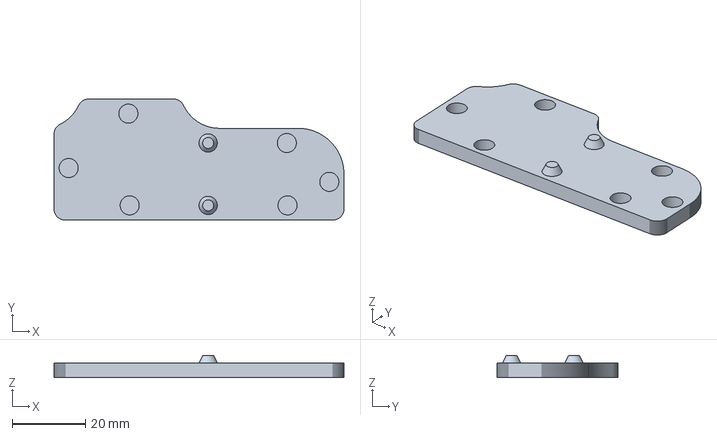
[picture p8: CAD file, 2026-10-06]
mechanical/wall-mount/planch-wall-base.step
79.0 x 33.0 x 6.00 mm

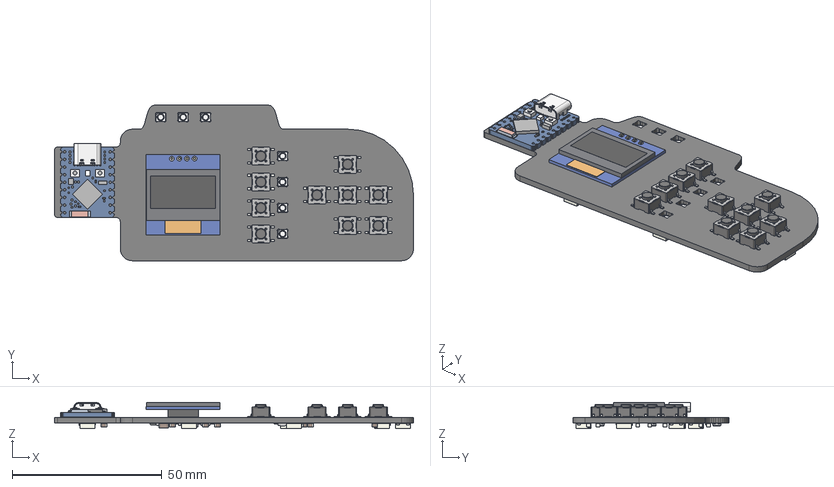
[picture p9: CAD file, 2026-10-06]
production/planch.step
120.0 x 52.0 x 8.70 mm
SW_SPST_PTS645Sx43SMTR92 x 10
pcb
header
pins
pads
glass
active
fpc
BOARD
EXTRUDED-21020 x 13
EXTRUDED-21415 x 7
3_1_A x 3
EXTRUDED-58116 x 2
EXTRUDED-58651
EXTRUDED-59046
EXTRUDED-59609
TYPE-C_16PIN-9X3X7_3
PRT0001
C3
BUTTON-2X3XH1_5
C_0805_2012Metric x 13
Pin1 x 7
Pin2 x 7
Pin3 x 7
Pin4 x 7
LED_SK6812_PLCC4_50x50mm_P32mm x 6
R_0805_2012Metric
C_1206_3216Metric
planch_PCB

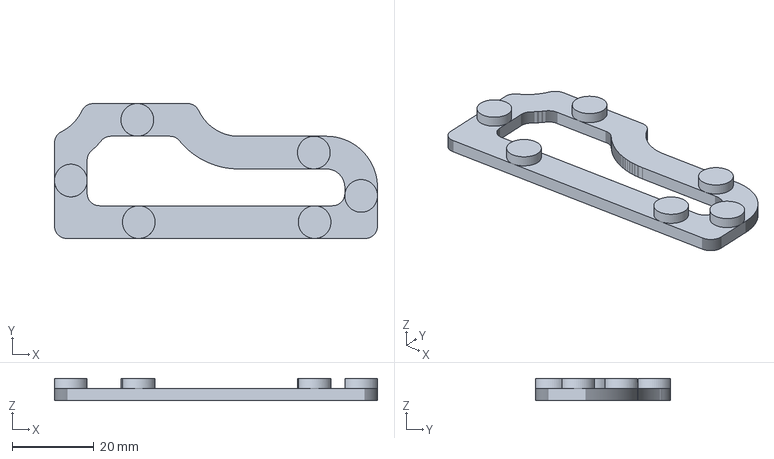
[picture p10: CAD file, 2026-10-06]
mechanical/wall-mount/planch-wall-bracket.step
79.0 x 33.0 x 5.40 mm

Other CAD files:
mechanical/desk-stand/planch-desk-stand.3mf
mechanical/desk-stand/planch-desk-stand.stl
mechanical/wall-mount/planch-wall-base.3mf
mechanical/wall-mount/planch-wall-base.stl
mechanical/wall-mount/planch-wall-bracket.3mf
mechanical/wall-mount/planch-wall-bracket.stl

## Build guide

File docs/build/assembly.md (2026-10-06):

# Assembly

From the bare PCB to a working button panel: work order, technique for each part, tricks for
the difficult ones and a test at every step.

**44 components + 6 feet · 2–3 hours for the first board · everything solderable with a
regular iron.**

<figure markdown="span">
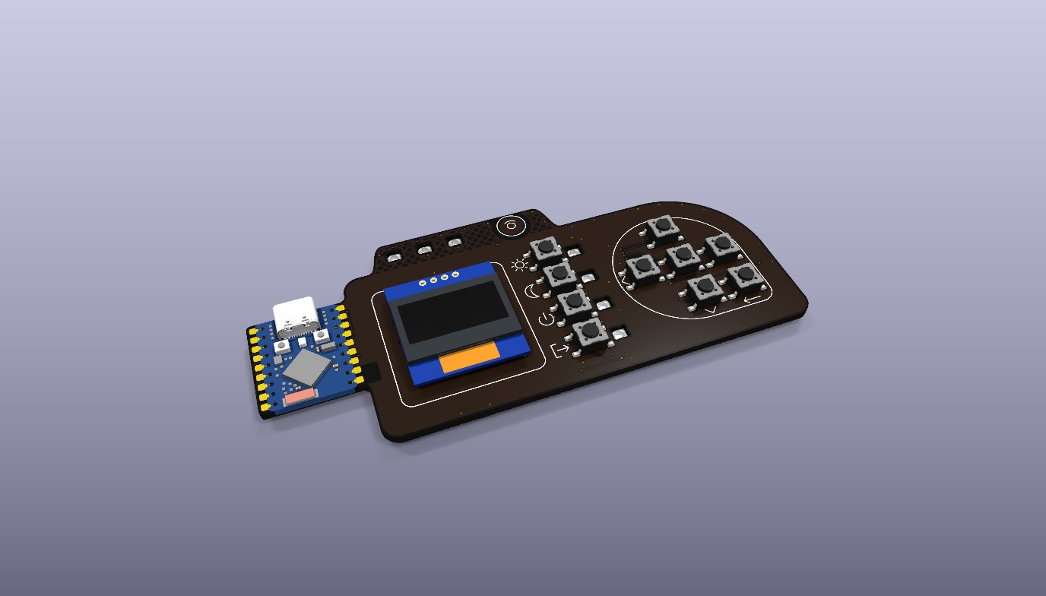
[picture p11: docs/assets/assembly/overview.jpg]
PlancH, assembled
  
  <figcaption>The result: ESP32 module on the left, display in the middle, scenes and
  directional pad on the right.</figcaption>
</figure>

<div class="grid" markdown>
<figure markdown="span">
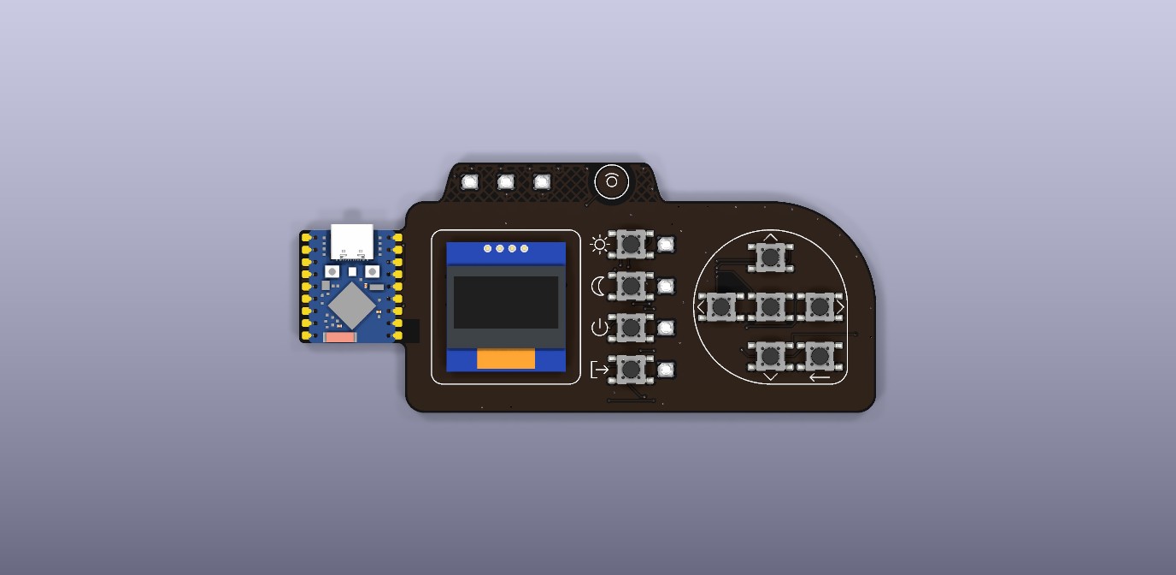
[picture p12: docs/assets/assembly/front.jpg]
Front of the board
  
  <figcaption>Front: module, display, 10 buttons, 7 LED windows, touch area.</figcaption>
</figure>
<figure markdown="span">
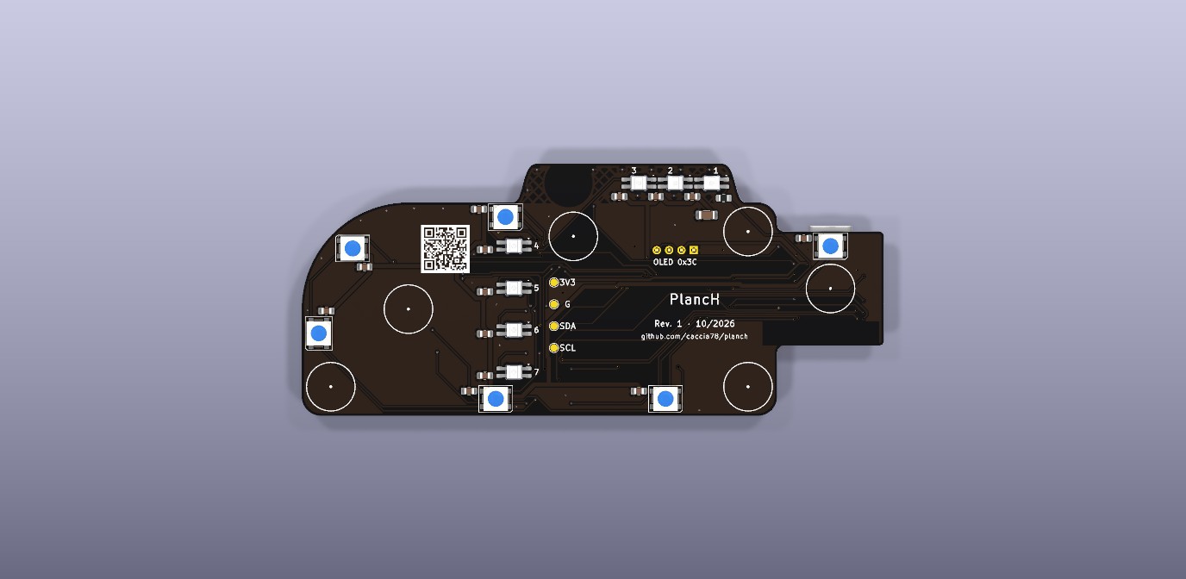
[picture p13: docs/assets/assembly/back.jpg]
Back of the board
  
  <figcaption>Back (seen from below): LEDs, passives, test pads, foot circles.</figcaption>
</figure>
</div>

## Components

| Ref. | Part | Qty | Side | Package | Difficulty |
| --- | --- | :-: | --- | --- | --- |
| U1 | Waveshare ESP32-S3-Zero (no headers) | 1 | Front | Castellated pads | Medium |
| U2 | 0.96" SSD1306 I²C OLED | 1 | Front | 4 through-hole pins | Medium |
| SW1–SW10 | 6 × 6 × 4.3 mm SMD switch (PTS645 or equivalent) | 10 | Front | Gull-wing | Easy |
| D1–D7 | SK6812MINI-E reverse mount | 7 | Back | 3.2 × 2.8 mm in a window | Hard |
| D8–D13 | 5050 RGB LED (SKC6812RV or WS2812B) | 6 | Back | PLCC4 5 × 5 mm | Medium |
| R1 | 330 Ω | 1 | Back | 0805 | Easy |
| C1–C13 | 100 nF X7R | 13 | Back | 0805 | Easy |
| C14 | 47 µF X5R 10 V | 1 | Back | 1206 | Easy |
| — | Adhesive feet Ø 10 × 5 mm | 6 | Back | Adhesive | — |

!!! info "Substitutions"
    WS2812B instead of SKC6812RV for D8–D13 (mind the orientation, see [step 5](#5-5050-leds-d8d13)),
    TDK C3216X5R1A476M160AB instead of the Samsung part for C14, generic 6 × 6 × 4.3 mm switches
    instead of the C&K ones. See [Components](components.md).

## Tools and materials

**Essential**

- Temperature-controlled soldering iron with a 1.6–2.4 mm chisel tip (passives, castellated
  pads, ground pads) and a 0.8–1 mm conical or fine chisel tip (LEDs).
- 0.5–0.6 mm flux-core solder. Leaded 63/37 or 60/40 melts at a lower temperature and is more
  forgiving; lead-free (SAC305) needs about 30–40 °C more.
- No-clean flux, gel or pen: the real secret for LEDs and castellated pads.
- Fine-tip anti-static tweezers, plus a curved pair.
- 1.5–2 mm desoldering braid.
- Flush cutters (for the OLED pins).
- Multimeter with continuity and diode test.
- A USB-C **data** cable and a computer with ESPHome.

**Very useful**

- Magnifier or microscope (×5–×10) to inspect the LED joints.
- PCB holder or "helping hands": once the module is on, the board no longer lies flat.
- Silicone mat or soft cloth: the matte black front scratches and stains easily.
- Kapton tape to hold parts and protect the front.
- Anti-static wrist strap: the LEDs are sensitive to electrostatic discharge.
- Isopropyl alcohol (≥ 99%), cotton swabs and a soft brush.
- Thick double-sided tape or a 2.5 mm spacer to align the OLED.

**Tip temperatures (indicative)**

| Job | Leaded solder | Lead-free | Contact time |
| --- | --- | --- | --- |
| 0805/1206 passives, switches | 310–330 °C | 340–360 °C | 2–3 s per joint |
| Ground pads, castellated pads | 330–350 °C | 360–380 °C | up to 4 s, wide tip |
| MINI-E and 5050 LEDs | 290–310 °C | 320–340 °C | ≤ 3 s, then let it cool |
| OLED pins | 310–330 °C | 340–360 °C | 2–3 s |

!!! tip
    The board has ground planes on both sides: pads connected to GND sink a lot of heat. A wide
    tip and a few more seconds work better than a fine tip at maximum temperature. If the joint
    stays dull and grainy, add flux and reflow.

## Preparation

- [ ] Inspect the bare PCB with a magnifier: clean edges on the 7 LED windows, no burrs, no
      scratches on the copper, readable silkscreen.
- [ ] Dry-fit a MINI-E LED in a window (from the back): it must drop in without force, with its
      legs resting on the pads. File off any burr with a fine needle file.
- [ ] With the multimeter in continuity mode, check for fabrication shorts between the pads of
      C14 (+5V and GND) and between TP1 (3V3) and TP2 (GND). It must not beep.
- [ ] Open the LED bag only when needed. MINI-Es are moisture sensitive (MSL 5a): if the bag
      has been open for a long time, the Opsco datasheet asks for baking at 70 °C for at
      least 12 hours before soldering.
- [ ] Prepare the assembly test firmware `firmware/planch-bringup.yaml` (see
      [Firmware](../firmware/index.md)): the Wi-Fi is set after flashing, no file to fill in.
- [ ] Work on a soft mat with the front protected: matte black solder mask shows every
      scratch and every drop of flux.

### Test firmware

To test LEDs and buttons as you go, without Home Assistant yet, use the assembly test firmware
[`firmware/planch-bringup.yaml`](https://github.com/caccia78/PlancH/blob/main/firmware/planch-bringup.yaml).
After the first USB flash, open the module's IP address in a browser: you will see the three
LED groups and the state of each button. LEDs not yet mounted are simply ignored. When the
board is complete you switch to the final firmware (step 8).

## Work order

From the lowest parts to the tallest, and the module early so the LED chain can be tested one
group at a time. A rotated LED or a cold joint breaks the whole chain after it: finding it
after 3 LEDs is much easier than after 13.

| # | Stage | Side | Test at the end |
| :-: | --- | --- | --- |
| 1 | Passives: R1, C14, C1–C13 | Back | No short between +5V and GND |
| 2 | ESP32-S3-Zero module | Front | Flash over USB, 5 V and 3.3 V rails |
| 3 | Status LEDs D1–D3 | Back | The 3 LEDs on the ear light up |
| 4 | Scene LEDs D4–D7 | Back | 7 LEDs light up |
| 5 | 5050 LEDs D8–D13 | Back | All 13 LEDs light up |
| 6 | Switches SW1–SW10 | Front | Every button changes state |
| 7 | OLED display | Front | "PlancH" on the display |
| 8 | Cleaning, touch calibration, feet | Both | Final test |

<div class="legend">
  <span><i style="background:var(--pl-pad-hl)"></i>pads to solder in this step</span>
  <span><i style="background:var(--pl-pad);opacity:.55"></i>other pads</span>
  <span><i style="border:2px solid var(--pl-pin1)"></i>pad 1 (GND on LEDs, + on C14)</span>
  <span><i style="background:var(--pl-chain)"></i>data path</span>
</div>

## 1 · Passives on the back

One resistor and 14 capacitors, all on the back and not polarised (C14 is ceramic). They go
first because they are the lowest: the board still lies flat on the mat, with the front
empty.

<figure class="diagram" markdown>
--8<-- "assembly/00-passives-back.svg"
<figcaption>Back seen from the solder side. C1–C13 sit next to each LED, R1 and C14 below D1
on the ear. The blue circle on C14 marks the +5V pad.</figcaption>
</figure>

<figure class="diagram" markdown>
--8<-- "assembly/01-passive-steps.svg"
<figcaption>The three-step method for SMD passives.</figcaption>
</figure>

- [ ] Put a touch of flux on one pad per component and tin it with a little solder (a small
      shiny bead, not a ball).
- [ ] Pick the part with tweezers, place it and reflow the tinned pad while sliding it into
      position. It must sit flat and centred.
- [ ] Solder the other pad with fresh solder, then touch up the first one for a concave, shiny
      fillet.
- [ ] Suggested order: R1 and C14 on the ear, then C1–C3, C4–C7 (scene column), C8–C13.
- [ ] Inspect with the magnifier: no bridges, no part lifted on one side (tombstoning).

!!! tip
    100 nF ceramic capacitors have no markings: keep the 100 nF and 47 µF tapes apart and take
    one part at a time. C14 (1206) is bigger; R1 has its value printed (331 or 3300).

!!! warning
    If C14 is an SMD electrolytic instead of a ceramic, it is polarised: the pad with the blue
    circle in the drawing is +5V (pad 1), the other is GND.

!!! success "Test"
    The multimeter across the C14 pads must not show a short circuit.

## 2 · ESP32-S3-Zero module

The module is soldered only by its 18 castellated edge pads, 9 per side, with the USB-C
towards the outside of the tab and the antenna at the bottom. The PCB pads extend about
1.4 mm beyond the edge of the module: that is where the iron works.

<div class="grid" markdown>
<figure class="diagram" markdown>
--8<-- "assembly/02-module-pads.svg"
<figcaption>Front: the 18 module pads. Top left is 5V, top right is TX (GP43), which stays
unconnected.</figcaption>
</figure>
<figure markdown="span">
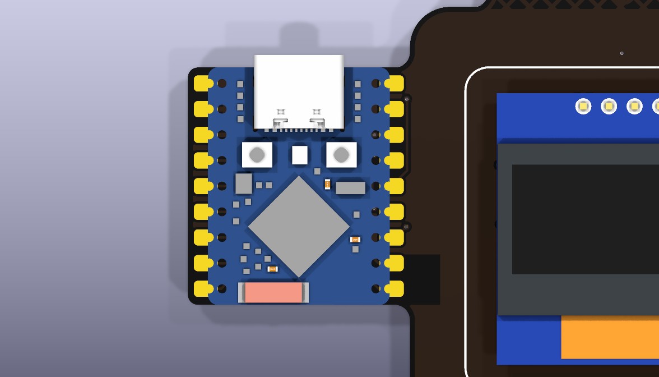
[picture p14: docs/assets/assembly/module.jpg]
Module on the board
  
  <figcaption>Module in place, USB beyond the top edge of the tab.</figcaption>
</figure>
</div>

<figure class="diagram" markdown>
--8<-- "assembly/03-castellated.svg"
<figcaption>Soldering a castellated pad.</figcaption>
</figure>

- [ ] Flux all 18 PCB pads.
- [ ] Lightly tin a single corner pad, for example GP6 (bottom left).
- [ ] Place the module: USB-C up, past the edge of the tab, module markings readable. Align
      the half-holes with the pads on both sides, looking against the light.
- [ ] Hold the module with a finger or a stick (not with tweezers on its components) and
      reflow the tinned pad.
- [ ] Check the alignment on all 18 pads. Reflow and correct if needed: this is the last easy
      moment to do it.
- [ ] Solder the opposite corner (TX, top right), then all the others: chisel tip on the pad
      and against the half-hole, solder fed from the opposite side of the tip.
- [ ] Check with the magnifier that solder has climbed into every half-hole and that there are
      no bridges between neighbouring pads (2.54 mm pitch).

!!! tip
    The solder should form a small ramp from the pad into the half-hole. If it stays as a ball
    on the pad without wetting the half-hole, add flux and hold the tip one more second,
    pressing lightly towards the module.

!!! warning
    - The module also has pads on its underside: they are not soldered and must not touch
      anything. Under the module the PCB has only solder mask and tented vias, but leave no
      solder drops there.
    - Do not solder with the USB cable plugged in.
    - The TX pad (GP43) has no connection: you can solder it for mechanical strength.

!!! success "Test"
    - Plug in USB: the computer must detect the device. If it does not, hold the module's BOOT
      button while plugging in the cable.
    - Flash with `esphome run firmware/planch-bringup.yaml`, then set the Wi-Fi from
      [web.esphome.io](https://web.esphome.io) (**Configure Wi-Fi**) or from the **PlancH**
      hotspot the board opens.
    - Measure about 5 V across the C14 pads and about 3.3 V between TP1 and TP2.
    - The ESPHome log shows the module joining Wi-Fi.

<figure markdown="span">
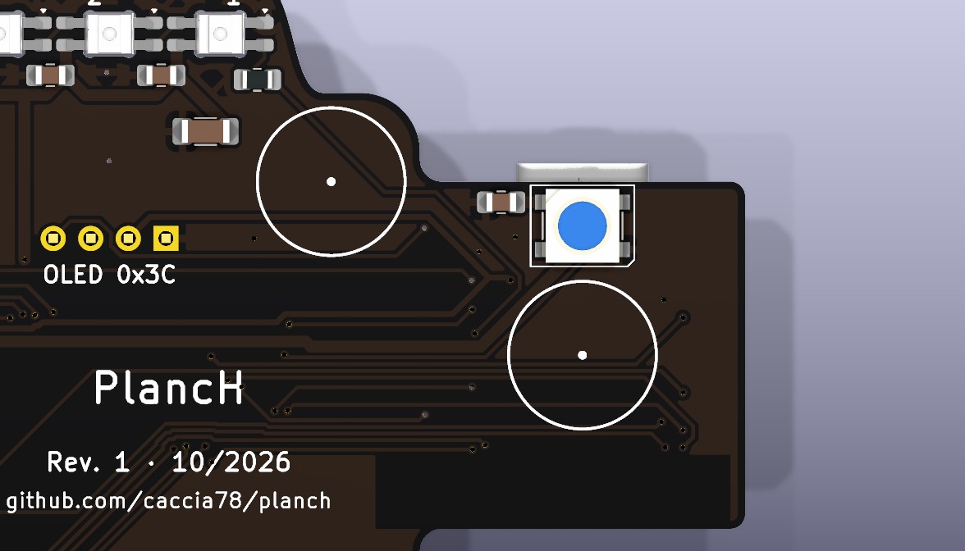
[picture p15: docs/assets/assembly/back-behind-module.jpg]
Back behind the module
  
  <figcaption>On the back, behind the module, are D13 and C13: they are soldered in step 5.
  The circle is foot F1.</figcaption>
</figure>

## 3 · Status LEDs D1–D3 (reverse mount)

The MINI-Es are the most delicate step. They are mounted from the back, upside down: the body
goes into the milled window, the lens faces the front and the four legs rest on the pads on
the back.

<figure class="diagram" markdown>
--8<-- "assembly/04-minie-section.svg"
<figcaption>Cross-section: LED inserted from the back into its window, board front-down on
the work surface.</figcaption>
</figure>

<div class="grid" markdown>
<figure class="diagram" markdown>
--8<-- "assembly/05-status-leds.svg"
<figcaption>Back of the ear: D1 is the closest to R1 and C14. The blue circle is pad 1 (GND),
marked on the silkscreen by a small triangle.</figcaption>
</figure>
<figure markdown="span">
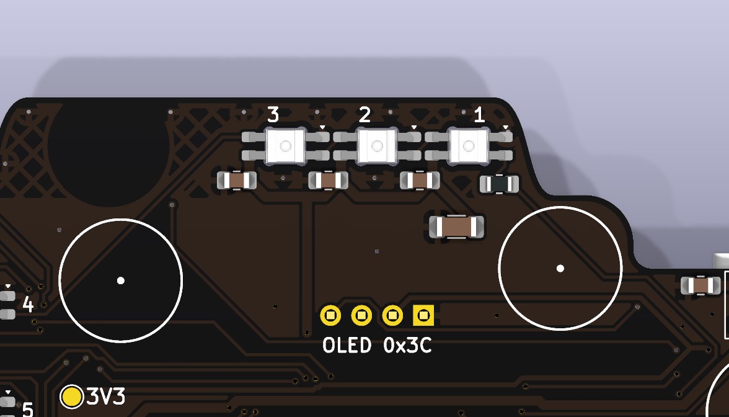
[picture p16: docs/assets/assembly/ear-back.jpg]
Back of the ear with the status LEDs
  
  <figcaption>Numbers 1–3, triangles on the GND pads, R1 and C14 below D1.</figcaption>
</figure>
</div>

**Orientation.** In the KiCad schematic the MINI-E pins are numbered 1 GND, 2 DIN, 3 VDD,
4 DOUT; the Opsco datasheet numbers them differently (1 VDD, 2 DOUT, 3 GND, 4 DIN), but the
physical position is the same. What matters: **the LED's GND pin goes on the pad with the
triangle.**

!!! tip "Finding GND"
    If you are not sure which pin is GND, use the multimeter's diode test: red probe on the GND
    pin and black on VDD usually reads about 0.5–0.7 V (internal protection diode); with the
    probes swapped it reads nothing. Try it on a spare LED before mounting.

- [ ] Lay the board front-down on the mat. If the module makes it rock, put a shim under the
      other end or use a holder: the ear area must lie flat.
- [ ] Flux the 4 pads of D1.
- [ ] With tweezers, drop D1 into the window, lens down, GND towards the triangle. The LED
      rests on its legs by itself.
- [ ] Centre the body in the window, then touch a single leg with the fine tip and very little
      solder: enough to hold it.
- [ ] Check from the front (lifting the board carefully) that the lens is centred in the
      window and not tilted. Correct it now if needed.
- [ ] Solder the other three legs: short contact (≤ 3 s), then touch up the first one.
- [ ] Repeat for D2 and D3. Pause between LEDs so the area does not overheat.

!!! warning
    - Never press on the lens or the body with tweezers or the iron: the silicone deforms and
      the die inside gets damaged.
    - Do not insist with heat: if the solder does not wet, lift the tip, add flux and try again
      after a few seconds.
    - Some solvents attack the resin: clean only with a little isopropyl alcohol, never
      acetone.

!!! success "Test"
    Power the module and switch on the **Status LEDs** group in the ESPHome web page: D1, D2
    and D3 must light up with the same colour. If only D1 lights up, check the DOUT joint of D1
    and the DIN joint of D2.

<figure markdown="span">
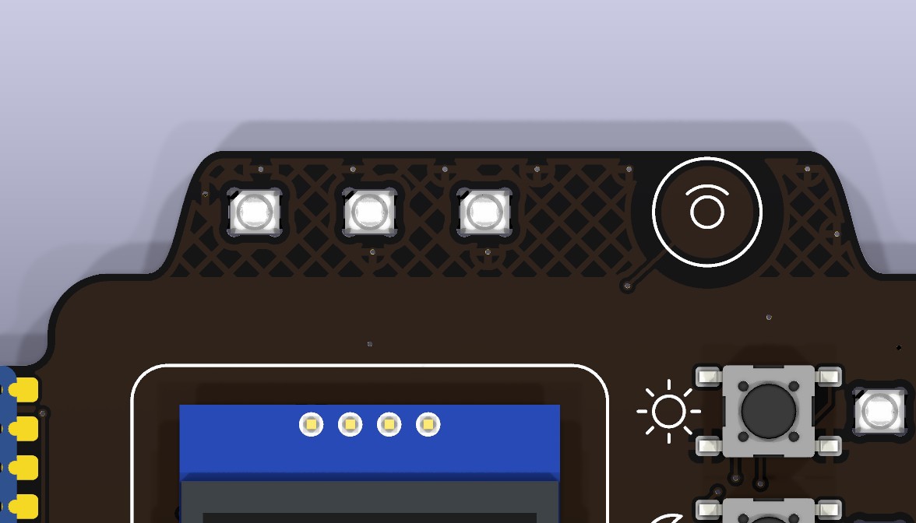
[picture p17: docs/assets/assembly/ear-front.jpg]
Front of the ear
  
  <figcaption>From the front: the three status LED windows and the touch area on the
  right.</figcaption>
</figure>

## 4 · Scene LEDs D4–D7

Same technique as the status LEDs. The four LEDs sit in a column next to the scene buttons,
each with its capacitor already soldered.

<div class="grid" markdown>
<figure class="diagram" markdown>
--8<-- "assembly/06-scene-leds.svg"
<figcaption>Back: D4 at the top (next to Scene 1), D7 at the bottom. The GND pad is always on
the same side.</figcaption>
</figure>
<figure markdown="span">
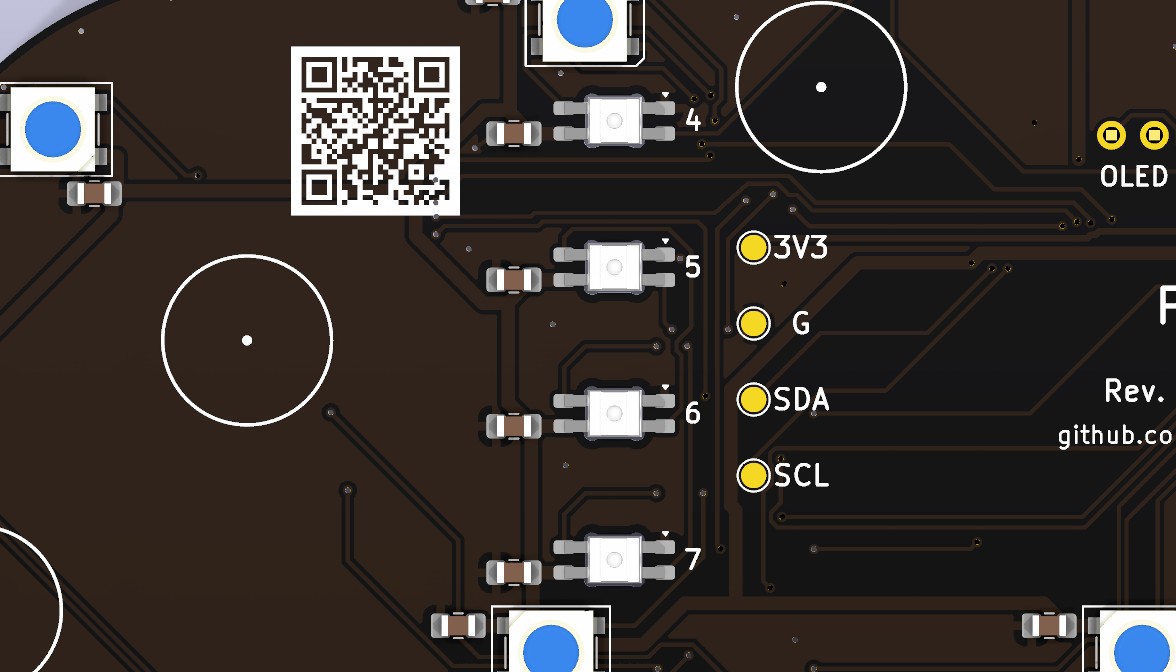
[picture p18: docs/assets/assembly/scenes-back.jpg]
Scene LED column on the back
  
  <figcaption>Numbers 4–7, test pads 3V3, G, SDA and SCL on the right.</figcaption>
</figure>
</div>

- [ ] Board front-down, column area flat.
- [ ] Mount D4, D5, D6 and D7 as for the status LEDs: one leg, check from the front, the
      other three.
- [ ] All four have the same orientation: compare them before soldering the second leg.

!!! success "Test"
    Switch on the **Scene LEDs** group: D4–D7 must light up. If the chain stops at a given LED,
    the fault is almost always in that LED or in the DOUT joint of the previous one.

<figure markdown="span">
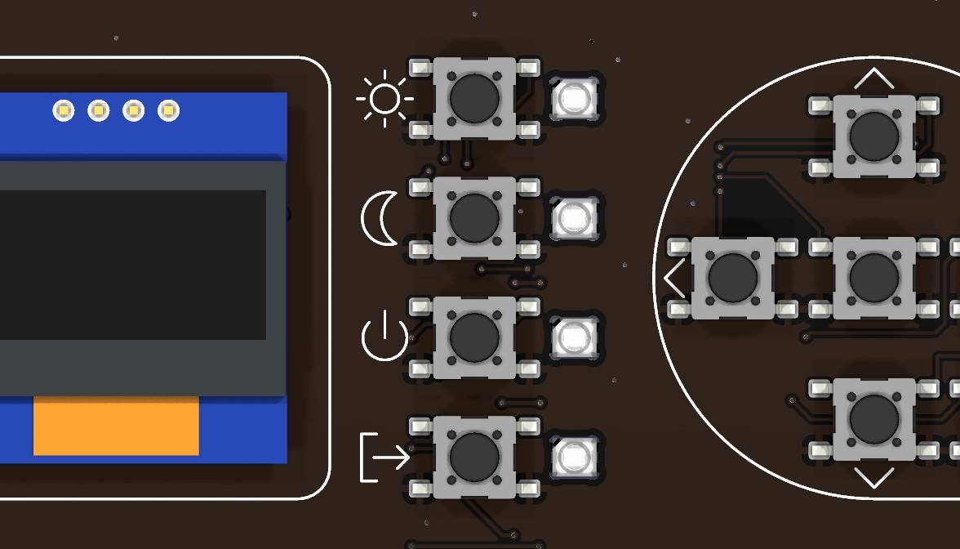
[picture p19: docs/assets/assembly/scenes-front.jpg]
Scene column from the front
  
  <figcaption>From the front: the windows to the right of each scene button.</figcaption>
</figure>

## 5 · 5050 LEDs D8–D13

The six backlight LEDs shine towards the desk. They are bigger and sturdier than the MINI-Es,
but have more thermal mass and four pads sticking out on the sides of the body.

<figure class="diagram" markdown>
--8<-- "assembly/07-led-chain.svg"
<figcaption>Back with the data path: R1 → D1 … D7 → D8 → D9 → D10 → D11 → D12 → D13. D9 is
rotated by 90°, D10 by 180°: always follow the chamfer on the silkscreen, not the direction of
the other LEDs.</figcaption>
</figure>

<div class="grid" markdown>
<figure markdown="span">
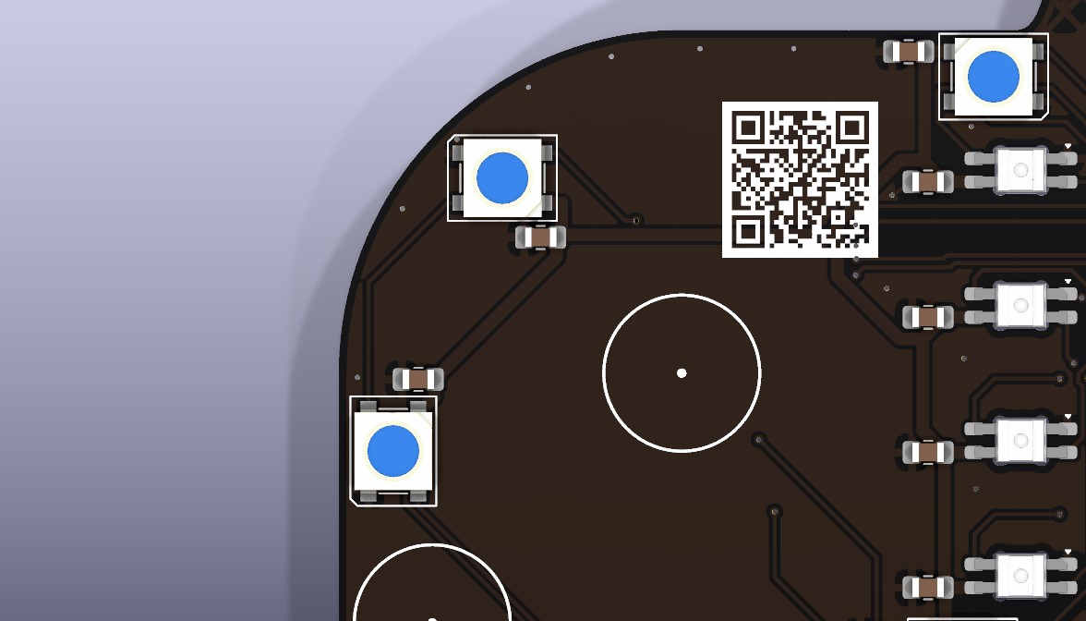
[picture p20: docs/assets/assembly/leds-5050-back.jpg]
5050 LEDs on the back
  
  <figcaption>D9, D10, D11 with the silkscreen chamfer on the pad 1 corner.</figcaption>
</figure>
<figure class="diagram" markdown>
--8<-- "assembly/08-5050-soldering.svg"
<figcaption>Soldering a 5050: the tip heats the part of the pad outside the body.</figcaption>
</figure>
</div>

**Orientation.**

- **SKC6812RV** (part in the BOM): pin 1 GND, 2 DIN, 3 VDD, 4 DOUT, same as the footprint.
  Pin 1 goes on the chamfered corner of the silkscreen.
- **WS2812B** (common alternative): numbered 1 VDD, 2 DOUT, 3 VSS, 4 DIN. The physical layout is
  the same rotated by 180°: **the VSS pin goes on the chamfered corner.** The mark on the
  WS2812B body may therefore not match the chamfer: orient it by function.

!!! tip "A test LED"
    Before mounting a new type of 5050, use the diode test (red on GND, black on VDD: about
    0.5–0.7 V) to find which corner is GND and compare it with the seller's datasheet drawing.

- [ ] Flux the 4 pads of the LED.
- [ ] Tin one corner pad, place the LED with the right chamfer and reflow the pad so it
      settles flat.
- [ ] Solder the other three pads heating the protruding part: the solder flows under the
      lead.
- [ ] GND pads are connected to the ground plane: use the widest tip and a few more seconds.
- [ ] Follow the chain order: D8, D9, D10, D11, D12, D13. D13 is behind the module.

!!! warning
    - RGBW LEDs are different: if one is RGBW by mistake, every colour after it is wrong.
    - Do not mix 5050 LEDs with different housings on the same board if you care about even
      light on the desk.

!!! success "Test"
    Switch on the **Backlight** group: all 6 downward LEDs must light up. Try pure red, green
    and blue to check that the colour order is right along the whole chain.

## 6 · Switches SW1–SW10

Ten identical switches, all at 0°, with legs on the left and right. Rotated by 180° a switch
works the same; rotated by 90° the legs miss the pads, so the orientation is forced.

<figure class="diagram" markdown>
--8<-- "assembly/09-buttons.svg"
<figcaption>Front: scene column SW7–SW10 and directional pad with OK in the centre and Back at
the bottom right.</figcaption>
</figure>

<div class="grid" markdown>
<figure markdown="span">
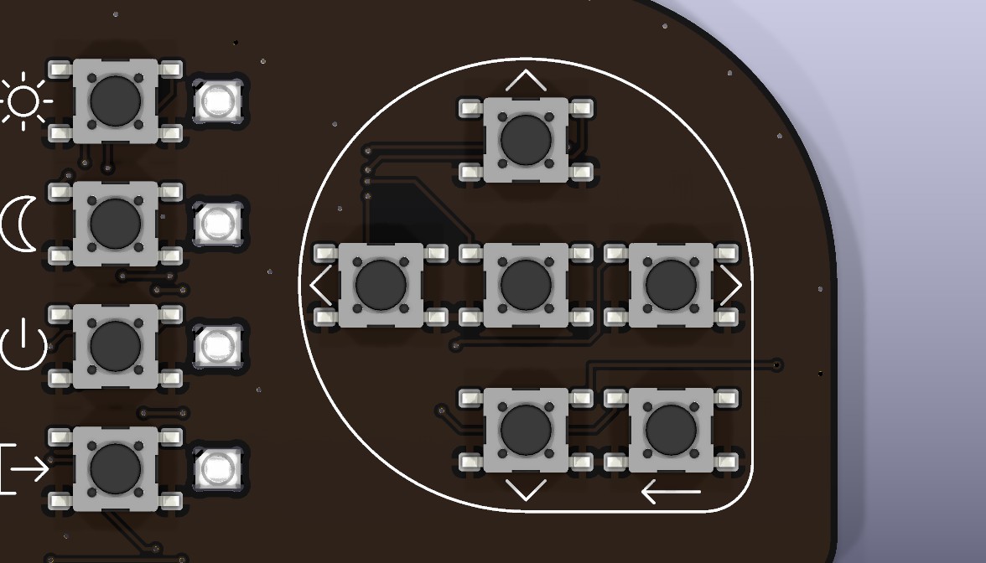
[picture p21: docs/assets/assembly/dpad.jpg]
Directional pad
  
  <figcaption>Directional pad at 10.25 mm pitch: SW3, SW5 and SW4 on the same row; SW1, SW5
  and SW2 on the same column.</figcaption>
</figure>
<figure markdown="span">
  Scene column
  <figcaption>Scene column at 8.67 mm pitch.</figcaption>
</figure>
</div>

- [ ] From now on the board is worked front-up: rest it on a support that does not press on the
      LEDs on the back (for example two strips of wood under the edges).
- [ ] Very little flux, only on the pads: flux that gets into the mechanism makes the button
      sticky.
- [ ] Tin one pad per switch (always the same one, for example top left).
- [ ] Place the switch, reflow the pad and press lightly on the body (not the actuator) so it
      sits flat.
- [ ] Before soldering the other legs, check the alignment with rows and columns: a ruler laid
      on the bodies makes it obvious.
- [ ] Solder the other three legs with short contact. The plastic body does not like long
      heat.
- [ ] Press every button: the click must be crisp and the same for all.

!!! tip
    Solder them in aligned groups (SW3, SW5, SW4, then SW1 and SW2, then SW6) and the scene
    column all together: keeping the same line is easier.

!!! success "Test"
    In the ESPHome web page every button must go to "ON" while pressed. If one stays always
    pressed, look for a solder bridge between the GND legs and the signal legs.

## 7 · OLED display

The OLED goes last: it is the tallest and most fragile part. It is held only by the row of
4 pins at the top, so its bottom edge must be supported to keep it parallel to the board.

<div class="grid" markdown>
<figure class="diagram" markdown>
--8<-- "assembly/10-oled-pins.svg"
<figcaption>Front: the pin row at the top. GND on the left (square pad), then VIN, SCK,
SDA.</figcaption>
</figure>
<figure class="diagram" markdown>
--8<-- "assembly/11-oled-side.svg"
<figcaption>Side view: header, temporary spacer under the bottom edge, pins trimmed flush on
the back.</figcaption>
</figure>
</div>

- [ ] Check the pin order on the module: it must be **GND, VIN, SCK, SDA** from the left, looking
      at the display from the front with the pins at the top. It matches the "OLED 0x3C"
      silkscreen on the back.
- [ ] Leave the protective film on the glass until the end.
- [ ] If the header is not already soldered to the module, solder it to the module first, with
      the plastic on the OLED component side.
- [ ] Insert the pins from the front. Put a temporary spacer as tall as the header plastic
      (about 2.5 mm) under the bottom edge of the module: a piece of thick double-sided tape
      or rubber.
- [ ] Flip the board and solder a single pin from the back. Check that the display is parallel
      and centred in the silkscreen frame, then solder the other three.
- [ ] Trim the pins flush with the cutters and briefly reflow each joint: nothing must stick
      out on the back to scratch the desk.
- [ ] Remove the temporary spacer, or leave it if it is double-sided tape and keeps the display
      parallel.

!!! tip
    If you trim the pins before soldering, the joint comes out lower and cleaner: insert, cut
    leaving 0.5 mm, then solder.

!!! warning
    Do not heat for long near the glass and do not clean the display with alcohol: the
    polariser film turns cloudy.

!!! success "Test"
    - With the module unpowered, measure between TP3 (SDA) and TP1 (3V3), then between TP4
      (SCL) and TP1: 2–10 kΩ means the OLED pull-ups are there.
    - Power on: the display shows "PlancH" and the ESPHome log finds the device at address
      0x3C.

## 8 · Cleaning, touch area and feet

<figure class="diagram" markdown>
--8<-- "assembly/12-feet-testpads.svg"
<figcaption>Back: circles of the 6 feet F1–F6 and test pads TP1–TP4.</figcaption>
</figure>

**Cleaning**

- No-clean flux can stay, but on matte black it leaves shiny stains: wipe them with a cotton
  swab barely dampened with isopropyl alcohol.
- No immersion, no ultrasonic cleaning: liquid and residue would get into the switches and
  the display.
- Around the LEDs use very little alcohol and let it dry well.

**Touch area.** The E1 electrode is a copper disc under the solder mask: nothing to solder.
Keep it clean, with no tape or flux residue.

- [ ] Clean flux residue on both sides.
- [ ] With the test firmware (`setup_mode: true` under `esp32_touch`) read the touch values in
      the log at rest and with a finger on the ear: the threshold goes about halfway.
- [ ] In the final firmware `firmware/planch.yaml` set that `threshold` and `setup_mode: false`,
      then flash it (USB or over Wi-Fi): from now on the display shows the menu, see
      [Home Assistant](../home-assistant/index.md).
- [ ] Clean the foot circles with alcohol, let them dry and stick the 6 feet centred on the
      silkscreen circles. Press each one for 10 seconds.
- [ ] Put the board on the desk: it must not rock and no LED must touch the surface.

!!! note
    The 5 mm feet keep the 5050 LEDs off the desk: the light spreads over the surface instead
    of making a spot.

## Final test

| Check | Where | Expected |
| --- | --- | --- |
| LED supply | C14 pads | 4.8–5.2 V with USB connected |
| Logic supply | TP1 – TP2 | 3.2–3.4 V |
| I²C pull-ups (board off) | TP3 – TP1, TP4 – TP1 | 2–10 kΩ |
| Display | ESPHome log | Device found at 0x3C, text visible |
| LED chain | Test firmware web page | 13 LEDs, pure colours correct |
| Buttons | Test firmware web page | 10 buttons, one state change per press |
| Touch | ESPHome log | Triggers only with a finger on the ear |
| Menu | Final firmware | Rooms and devices from Home Assistant on the display |

Then follow [Home Assistant](../home-assistant/index.md) to choose the devices and the scenes
of the panel.

## Troubleshooting

| Symptom | Likely cause | Fix |
| --- | --- | --- |
| The computer does not see the module | Charge-only cable, module not in download mode | Data cable; hold BOOT while plugging in USB |
| No LED lights up | R1 or D1 not soldered, D1 rotated | Check R1, the orientation of D1 and the 5 V on C14 |
| The chain stops at LED N | LED N rotated or cold DIN/DOUT joint | Reflow DOUT of LED N-1 and DIN of LED N with flux; then check the orientation of LED N |
| Wrong colours after a given LED | An RGBW LED in the chain | Replace it with an RGB one |
| The first LED flickers or shows random colours | 3.3 V data signal at the edge of the threshold | Try another D1; if it persists, a level shifter is needed (design change) |
| A button is always pressed | Solder bridge or flux in the mechanism | Remove the bridge with braid; if the click is soft, replace the switch |
| Black display | Pin order, cold joint, different address | Check GND/VIN/SCK/SDA; the I²C log shows the address found |
| The touch triggers by itself | Threshold too close to the resting value | Repeat the calibration with `setup_mode: true` |
| A MINI-E lens tilted in its window | LED soldered at an angle | Reflow one leg at a time with flux, pushing the LED with a wooden stick |

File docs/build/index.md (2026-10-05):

# Build your own

Building a PlancH takes four steps:

1. **[Get the components](components.md)**: about 45 parts, most of them cheap and common.
2. **[Order the PCB](ordering.md)**: upload the Gerber ZIP to any PCB maker; only the bare board,
   no assembly service needed.
3. **[Assemble](assembly.md)**: everything is soldered by hand with a regular soldering iron.
   Plan 2–3 hours for the first board.
4. **[Flash the firmware](../firmware/index.md)** and add the board to Home Assistant.

Optionally, print the [desk stand](../accessories/desk-stand.md).

## Skills and tools

You should be comfortable with SMD soldering: 0805 passives, castellated pads and a few
small LEDs. A temperature-controlled iron, flux, fine tweezers and a magnifier are enough; no
hot air station or reflow oven is required. The [assembly guide](assembly.md#tools-and-materials)
has the full list.

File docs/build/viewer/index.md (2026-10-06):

# 3D Viewer

Explore the complete PlancH circuit board in 3D. Rotate, zoom, and inspect every component, connection, and detail.
Switch on the LEDs by group, as in the firmware, and turn the board over to see the backlight.

--8<-- "model-viewer.html"

<div style="margin: 2rem 0 0.5rem; border: 1px solid var(--md-border-color); border-radius: 8px; overflow: hidden;">
  <model-viewer 
    id="planch-3d"
    src="/PlancH/assets/planch-viewer.glb"
    alt="PlancH 3D model"
    auto-rotate
    camera-controls
    style="width: 100%; height: 600px; display: block;">
    <!-- HDR rendering: only the LEDs, with emissive strength above 1, pass the threshold -->
    <effect-composer render-mode="quality">
      <bloom-effect strength="0.8" threshold="3" radius="0.6"></bloom-effect>
    </effect-composer>
  </model-viewer>
</div>

<p>
  <button type="button" class="md-button" data-viewer-background="planch-3d" aria-pressed="false">Dark background</button>
</p>
<p id="planch-led-controlli">
  LEDs:
  <button type="button" class="md-button" data-led="led_stato" aria-pressed="false">Status</button>
  <button type="button" class="md-button" data-led="led_scene" aria-pressed="false">Scenes</button>
  <button type="button" class="md-button" data-led="led_retro" aria-pressed="false">Backlight</button>
  <label>Colour <input type="color" value="#ff7043"></label>
</p>

<script>planchLeds("planch-3d", "planch-led-controlli");</script>

Use your mouse to:

- **Rotate** — Click and drag
- **Zoom** — Scroll wheel  
- **Pan** — Right-click and drag

## About this model

The 3D model includes:

- **PCB** — 120 × 44 mm + 8 mm ear, 2.0 mm thickness with black solder mask and white silkscreen
- **Components** — ESP32-S3 module, OLED display, 10 tactile buttons, 13 addressable RGB LEDs
- **Silkscreen** — Front frame, scene button icons, touch area indicator, rear component labels

## Desk stand

The desk stand (leggio) is designed to hold PlancH at a 20° angle. You can [learn more](../../accessories/desk-stand.md) about printing and assembling it.

## Source files

The 3D model is exported directly from the KiCad PCB design using `kicad-cli`. All dimensions and placements match the actual board. Source files are on [GitHub](https://github.com/caccia78/PlancH/tree/main/hardware).

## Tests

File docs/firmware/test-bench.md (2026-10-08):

# Try it without the hardware

You can try PlancH with your own Home Assistant before building one: the same firmware runs on
any ESP32 development board with nothing connected (the "test bench"), and a Home Assistant card
draws the panel on its picture. The display shows your rooms and devices, the LEDs light up, and
you press the keys on the screen.

<figure markdown="span">
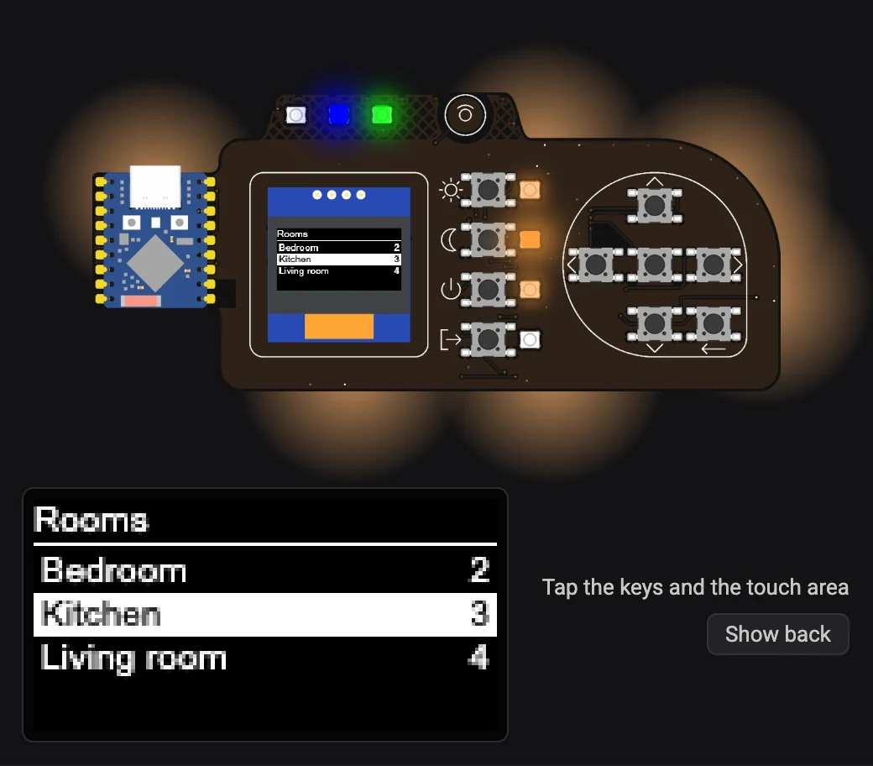
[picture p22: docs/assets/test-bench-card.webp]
The PlancH card in Home Assistant
  
  <figcaption>The PlancH card: display (enlarged below), LEDs, backlight glow, keys to tap.</figcaption>
</figure>

It is also how the firmware is developed: everything on the
[Firmware](index.md) and [Home Assistant](../home-assistant/index.md) pages works the same way.

## What you need

- A classic **ESP32** development board (ESP-WROOM-32, "ESP32 DevKit" and similar). The ESP32-S3
  is not needed: that is for the real PlancH.
- A USB **data** cable, and Chrome or Edge on a computer.
- Home Assistant with the [PlancH package](../home-assistant/index.md#1-install-the-planch-package)
  installed and a few devices with the label **PlancH**.

## 1 · Install the test bench

<script type="module" src="https://unpkg.com/esp-web-tools@10.4.0/dist/web/install-button.js?module"></script>

<p>
  <esp-web-install-button manifest="/PlancH/firmware/install/manifest-test.json">
    <span slot="unsupported">This browser cannot talk to USB devices: open the page in Chrome or Edge on a computer.</span>
    <span slot="not-allowed">The installer needs a secure (https) page.</span>
  </esp-web-install-button>
</p>

1. Connect the board and press **Connect**. Many ESP32 boards do not enter programming mode by
   themselves: if the installer stops at "Connecting…", hold the **BOOT** button while it
   connects.
2. Choose **Install PlancH test bench**, then **Configure Wi-Fi** at the end.
3. Home Assistant finds **PlancH test** under **Settings → Devices & services**: add it, then
   open its options (**Configure**) and enable **Allow the device to perform Home Assistant
   actions**.

The board shows up with a button for each key (Up, Down, Left, Right, OK, Back, Scene 1–4,
Touch), two text sensors with what the display and the 13 LEDs would show (**Screen** and
**LEDs**), and the lights **Status LED 2**, **Status LED 3** and **Backlight**.

## 2 · Install the card

1. Copy the folder
   [`homeassistant/www/planch/`](https://github.com/caccia78/PlancH/tree/main/homeassistant/www/planch)
   (`planch-card.js` and the two pictures) into the `www` folder of your Home Assistant
   configuration (next to `configuration.yaml`), so that you have `www/planch/planch-card.js`.
   If the `www` folder did not exist, restart Home Assistant once.
2. **Settings → Dashboards → ⋮ → Resources → Add resource**: URL
   `/local/planch/planch-card.js?v=1.1`, type **JavaScript module**. (No Resources menu? Turn on
   *Advanced mode* in your user profile.)
3. Reload the browser page.

!!! tip "After updating the card"
    Browsers keep the old card in their cache: after copying a new `planch-card.js`, change the
    number after `?v=` in the resource URL and reload. The browser console shows the version that
    is loaded (**PLANCH-CARD 1.1**).

## 3 · Add the card to a dashboard

The quickest way is the ready-made dashboard
[`homeassistant/planch-test-dashboard.yaml`](https://github.com/caccia78/PlancH/blob/main/homeassistant/planch-test-dashboard.yaml):
create a new dashboard, open **⋮ → Edit dashboard → ⋮ → Raw configuration editor** and paste the
file. It has the card with the lights of the panel, and a second view with the same data as text.

Or add the card to any dashboard:

```yaml
type: custom:planch-card
device: planch_test   # prefix of the entity IDs of the board
```

| Option | Default | Meaning |
| --- | --- | --- |
| `device` | `planch_test` | Prefix of the entity IDs (`sensor.<device>_screen`, `button.<device>_ok`, …) |
| `screen`, `leds` | from `device` | The two text sensors, if they have other IDs |
| `buttons` | `button.<device>_` | Prefix of the key buttons |
| `images` | `/local/planch` | Folder of the two pictures |
| `zoom` | `true` | `false` hides the enlarged display under the board |

## Using it

- **Tap** the keys and the touch area on the picture: the display and the LEDs answer as on the
  real panel. The display is also drawn larger under the board, since the real one is only
  22 × 11 mm.
- **Show back** turns the board over: the six backlight LEDs on the back, lit with the colour of
  the **Backlight** light. On the front they show as a glow around the board.
- The keys and LEDs behave as described on the [Firmware](index.md#keys-and-display) page.

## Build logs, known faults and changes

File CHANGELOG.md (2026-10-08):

# Changelog

All notable changes to PlancH are listed here. Hardware revisions match the "Rev." printed on
the back of the board.

## [Unreleased]

### Hardware — Rev. 1

- First public release of the design: 120 × 52 mm PCB, Waveshare ESP32-S3-Zero, SSD1306 OLED,
  10 buttons, capacitive touch area, 13 SK6812 RGB LEDs.
- Production files: Gerber, drill, BOM, pick-and-place, interactive BOM, schematic PDF, STEP.

### Accessories

- Desk stand: 3D-printed frame that holds the board at 20°, with light slots for the backlight.
- Wall mount: ring bracket glued behind the board and a base stuck to the wall, held by magnets;
  the backlight shines on the wall around it.

### Firmware

- Menu built automatically from Home Assistant: devices chosen with the label "PlancH", grouped
  by room and type (lights, covers, thermostats); scene keys assigned with the labels
  "PlancH S1"–"PlancH S4". Home Assistant package in `homeassistant/planch.yaml`.
- LEDs: D1 shows problems, D2–D3 and the backlight are lights for Home Assistant automations,
  the scene LEDs show the active scene and confirm each press.
- Wi-Fi set after flashing (web.esphome.io or the board's hotspot): no password in the files.
- Assembly test firmware `planch-bringup.yaml` (buttons, touch, display, LED groups) and a test
  bench `planch-test.yaml` that runs the menu on any ESP32 board.
- Colour lights: rows Brightness, Colour (palette editable in the package), White and Effect on the
  screen of a light; Up/Down scroll through the rows and on to the next light.
- The menu follows label and area changes by itself (automation in the package).
- Switches (smart plugs) in the menu, under "Switches".
- More than one PlancH in the same home: the label "PlancH" for devices on every panel,
  "PlancH <name>" for one panel only; the name is set in the "Panel" field on the device page.
  Scene keys per panel with "PlancH <name> S1" … "S4". Panels installed from the browser get a
  unique name (planch-xxxxxx).
- Install from the browser: the Firmware page installs PlancH on its ESP32-S3; a separate page,
  "Try it without the hardware", installs the test bench on a classic ESP32.
- Home Assistant card `planch-card`: the panel drawn on its picture, with display, LEDs,
  backlight glow and keys to tap.

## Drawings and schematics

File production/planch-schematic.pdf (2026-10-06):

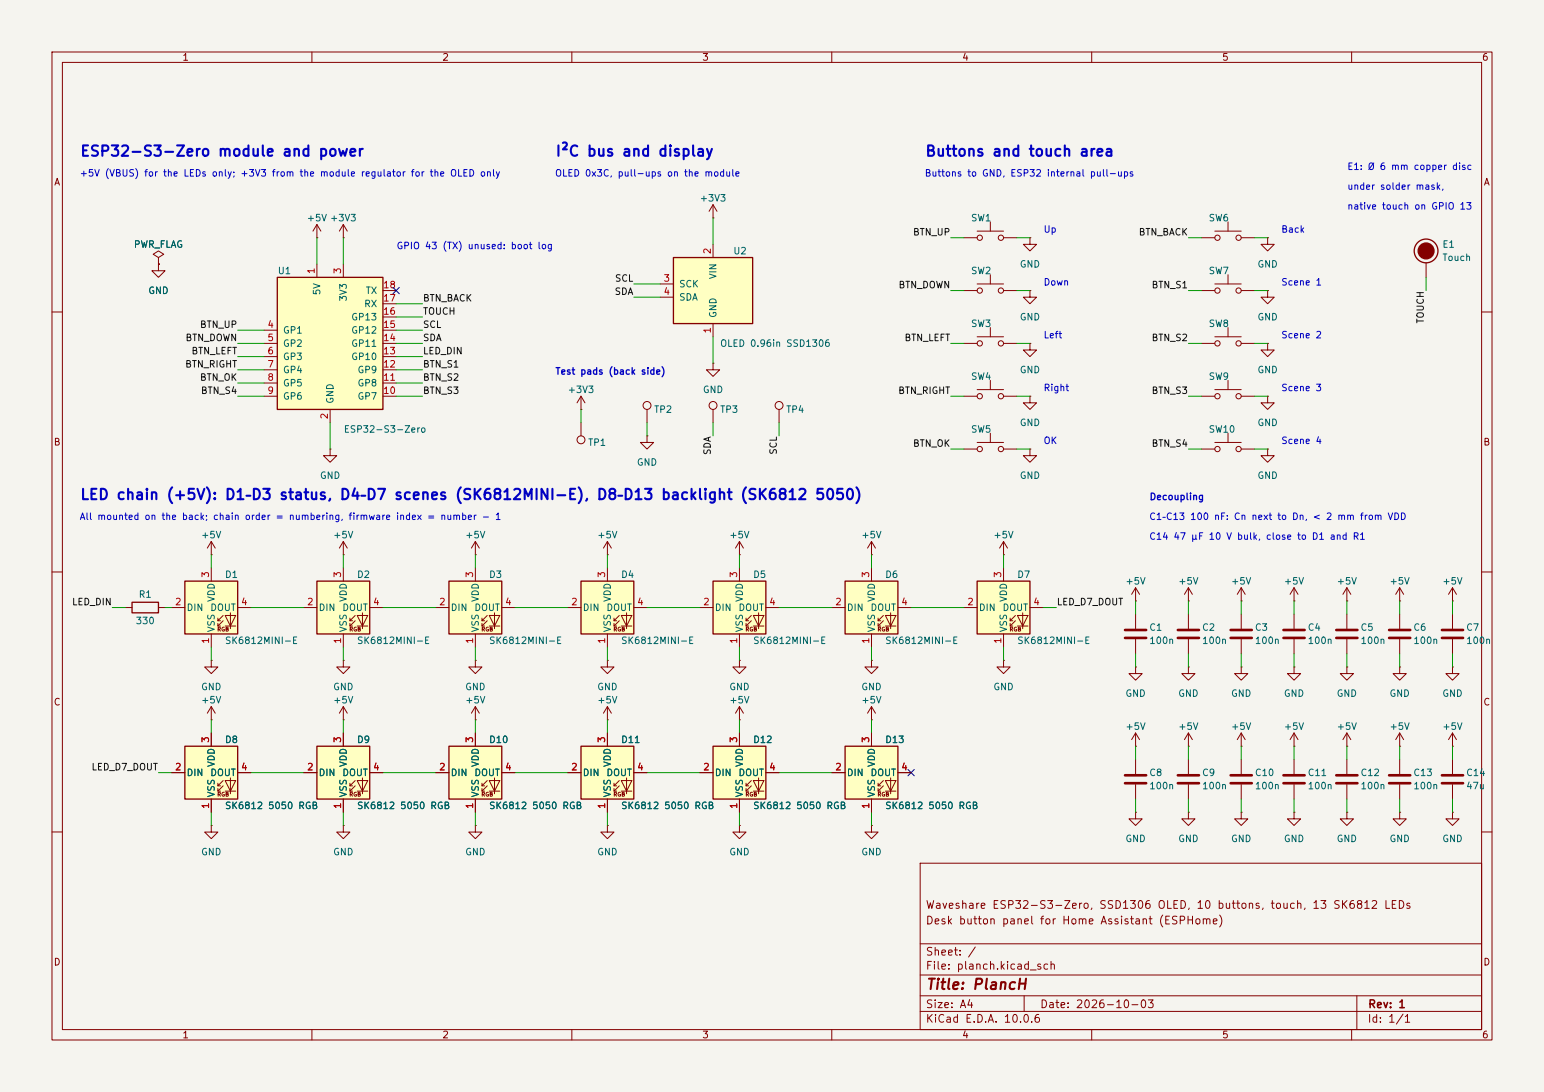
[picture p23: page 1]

ESP32-S3-Zero module and power
E1: Ø 6 mm copper disc +5V (VBUS) for the LEDs only; +3V3 from the module regulator for the OLED only

I²C bus and display

native touch on GPIO 13 OLED 0x3C, pull-ups on the module

Buttons to GND, ESP32 internal pull-ups

Left OK LED chain (+5V): D1–D3 status, D4–D7 scenes (SK6812MINI-E), D8–D13 backlight (SK6812 5050)

Desk button panel for Home Assistant (ESPHome)

Size: A4 | Rev: 1
KiCad E.D.A. 10.0.6 | Id: 1/1

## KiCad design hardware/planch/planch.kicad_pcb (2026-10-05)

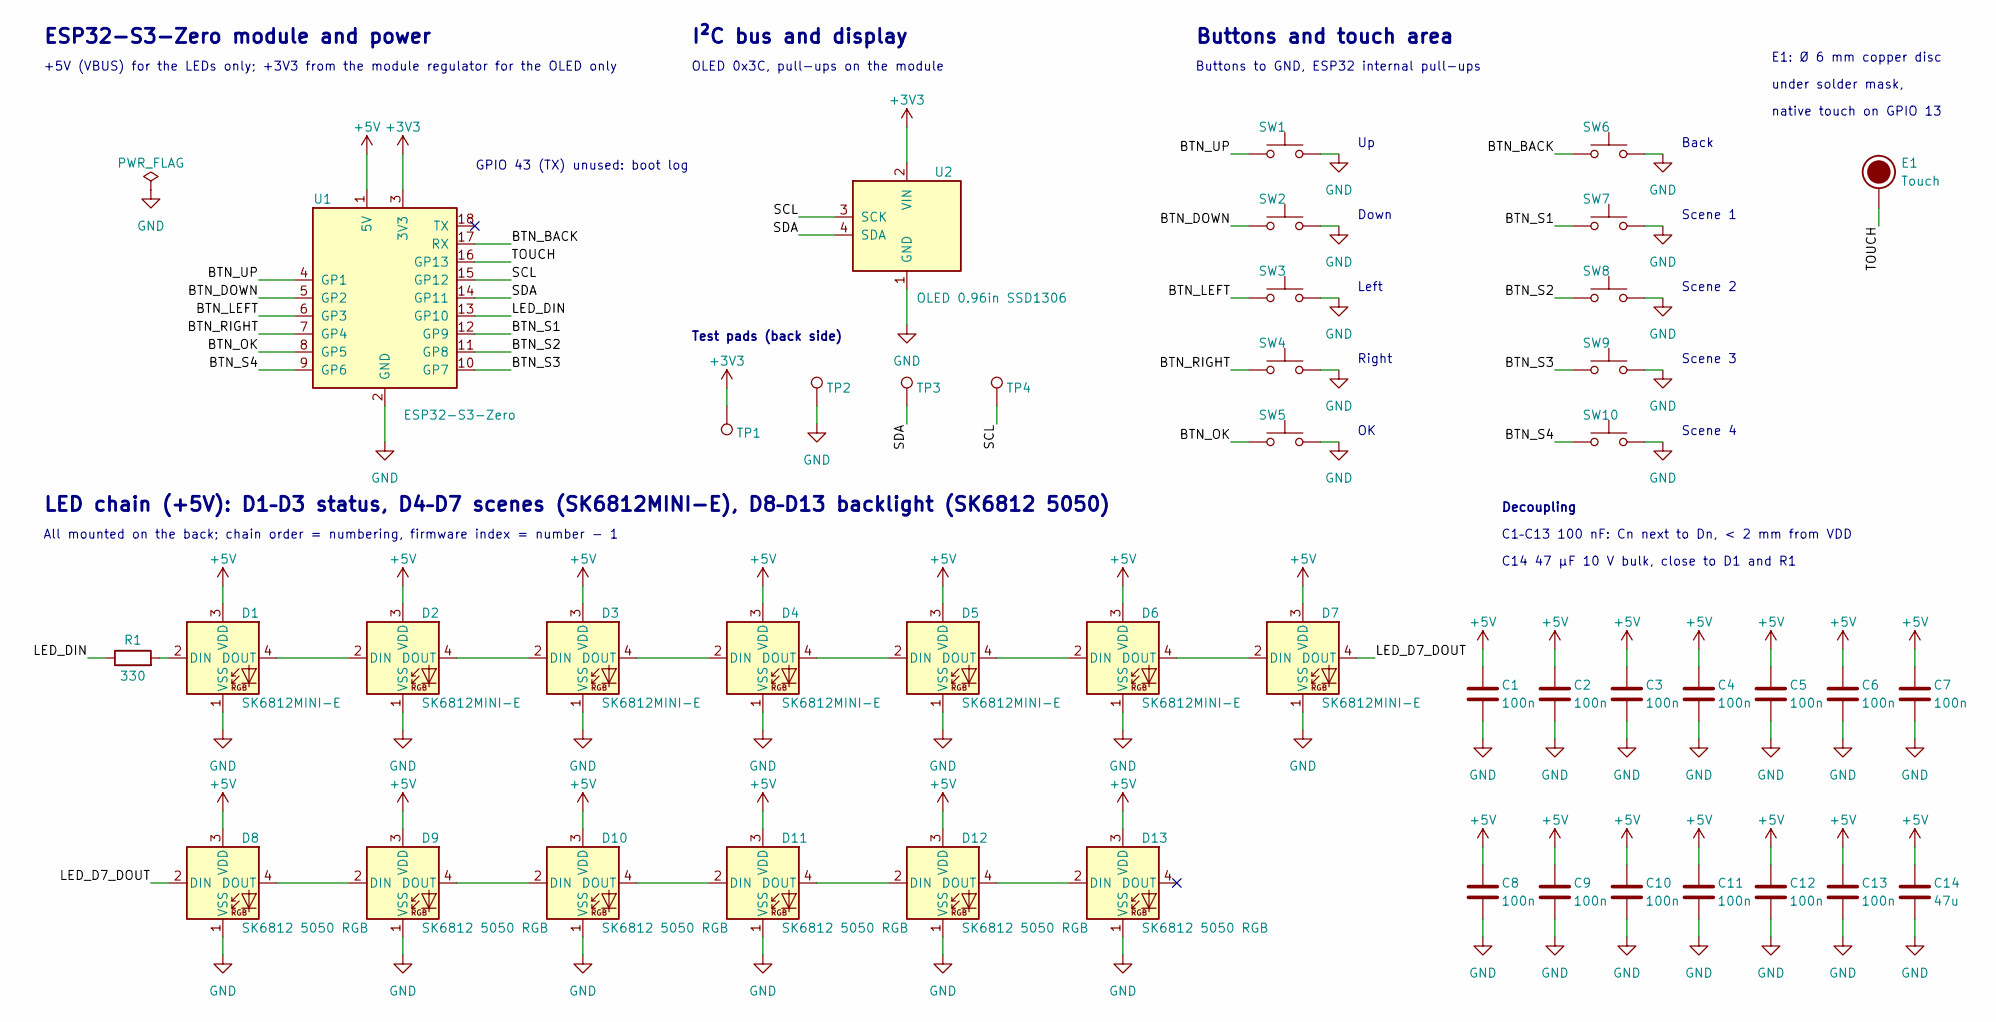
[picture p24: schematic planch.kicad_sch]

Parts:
C1, C2, C3, C4, C5, C6, C7, C8, C9, C10, C11, C12, C13: 100n; C_0805_2012Metric_Pad1.18x1.45mm_HandSolder; MPN CL21B104KBCNNNC
C14: 47u; C_1206_3216Metric_Pad1.33x1.80mm_HandSolder; MPN CL31A476MPHNNNE
D1, D2, D3, D4, D5, D6, D7: SK6812MINI-E; LED_SK6812MINI-E_3.2x2.8mm_P1.5mm_ReverseMount_HandSolder; MPN SK6812MINI-E
D8, D9, D10, D11, D12, D13: SK6812 5050 RGB; LED_SK6812_PLCC4_5.0x5.0mm_P3.2mm; MPN SKC6812RV
E1: Touch; TouchPad_D6mm_Covered
R1: 330; R_0805_2012Metric_Pad1.20x1.40mm_HandSolder; MPN RC0805FR-07330RL
SW1, SW2, SW3, SW4, SW5, SW6, SW7, SW8, SW9, SW10: PTS645SH43; SW_SPST_PTS645Sx43SMTR92_NoSilk; MPN PTS645SH43SMTR92 LFS
TP1: 3V3; TestPoint_Pad_D1.5mm
TP2: GND; TestPoint_Pad_D1.5mm
TP3: SDA; TestPoint_Pad_D1.5mm
TP4: SCL; TestPoint_Pad_D1.5mm
U1: ESP32-S3-Zero; Waveshare_ESP32-S3-Zero_Castellated; MPN ESP32-S3-Zero
U2: OLED 0.96in SSD1306; OLED_SSD1306_0.96in_I2C_24.8x26.9mm; MPN SSD1306 0.96in I2C module

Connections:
+3V3: TP1.1 (1_1), U1.3 (3V3), U2.2 (VIN)
+5V: C1.1, C2.1, C3.1, C4.1, C5.1, C6.1, C7.1, C8.1, C9.1, C10.1, C11.1, C12.1, C13.1, C14.1, D1.3 (VDD), D2.3 (VDD), D3.3 (VDD), D4.3 (VDD), D5.3 (VDD), D6.3 (VDD), D7.3 (VDD), D8.3 (VDD), D9.3 (VDD), D10.3 (VDD), D11.3 (VDD), D12.3 (VDD), D13.3 (VDD), U1.1 (5V)
/BTN_BACK: SW6.1, U1.17 (RX)
/BTN_DOWN: SW2.1, U1.5 (GP2)
/BTN_LEFT: SW3.1, U1.6 (GP3)
/BTN_OK: SW5.1, U1.8 (GP5)
/BTN_RIGHT: SW4.1, U1.7 (GP4)
/BTN_S1: SW7.1, U1.12 (GP9)
/BTN_S2: SW8.1, U1.11 (GP8)
/BTN_S3: SW9.1, U1.10 (GP7)
/BTN_S4: SW10.1, U1.9 (GP6)
/BTN_UP: SW1.1, U1.4 (GP1)
/LED_D7_DOUT: D7.4 (DOUT), D8.2 (DIN)
/LED_DIN: R1.1, U1.13 (GP10)
/SCL: TP4.1 (1_1), U1.15 (GP12), U2.3 (SCK)
/SDA: TP3.1 (1_1), U1.14 (GP11), U2.4 (SDA)
/TOUCH: E1.1, U1.16 (GP13)
GND: C1.2, C2.2, C3.2, C4.2, C5.2, C6.2, C7.2, C8.2, C9.2, C10.2, C11.2, C12.2, C13.2, C14.2, D1.1 (VSS), D2.1 (VSS), D3.1 (VSS), D4.1 (VSS), D5.1 (VSS), D6.1 (VSS), D7.1 (VSS), D8.1 (VSS), D9.1 (VSS), D10.1 (VSS), D11.1 (VSS), D12.1 (VSS), D13.1 (VSS), SW1.2, SW2.2, SW3.2, SW4.2, SW5.2, SW6.2, SW7.2, SW8.2, SW9.2, SW10.2, TP2.1 (1_1), U1.2 (GND), U2.1 (GND)
unnamed: D1.2 (DIN), R1.2
unnamed: D1.4 (DOUT), D2.2 (DIN)
unnamed: D2.4 (DOUT), D3.2 (DIN)
unnamed: D3.4 (DOUT), D4.2 (DIN)
unnamed: D4.4 (DOUT), D5.2 (DIN)
unnamed: D5.4 (DOUT), D6.2 (DIN)
unnamed: D6.4 (DOUT), D7.2 (DIN)
unnamed: D8.4 (DOUT), D9.2 (DIN)
unnamed: D9.4 (DOUT), D10.2 (DIN)
unnamed: D10.4 (DOUT), D11.2 (DIN)
unnamed: D11.4 (DOUT), D12.2 (DIN)
unnamed: D12.4 (DOUT), D13.2 (DIN)

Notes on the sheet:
ESP32-S3-Zero module and power
+5V (VBUS) for the LEDs only; +3V3 from the module regulator for the OLED only
GPIO 43 (TX) unused: boot log
I²C bus and display
OLED 0x3C, pull-ups on the module
Test pads (back side)
Buttons and touch area
Buttons to GND, ESP32 internal pull-ups
Down
Left
Right
Back
Scene 1
Scene 2
Scene 3
Scene 4
E1: Ø 6 mm copper disc
under solder mask,
native touch on GPIO 13
LED chain (+5V): D1–D3 status, D4–D7 scenes (SK6812MINI-E), D8–D13 backlight (SK6812 5050)
All mounted on the back; chain order = numbering, firmware index = number − 1
Decoupling
C1–C13 100 nF: Cn next to Dn, < 2 mm from VDD
C14 47 µF 10 V bulk, close to D1 and R1

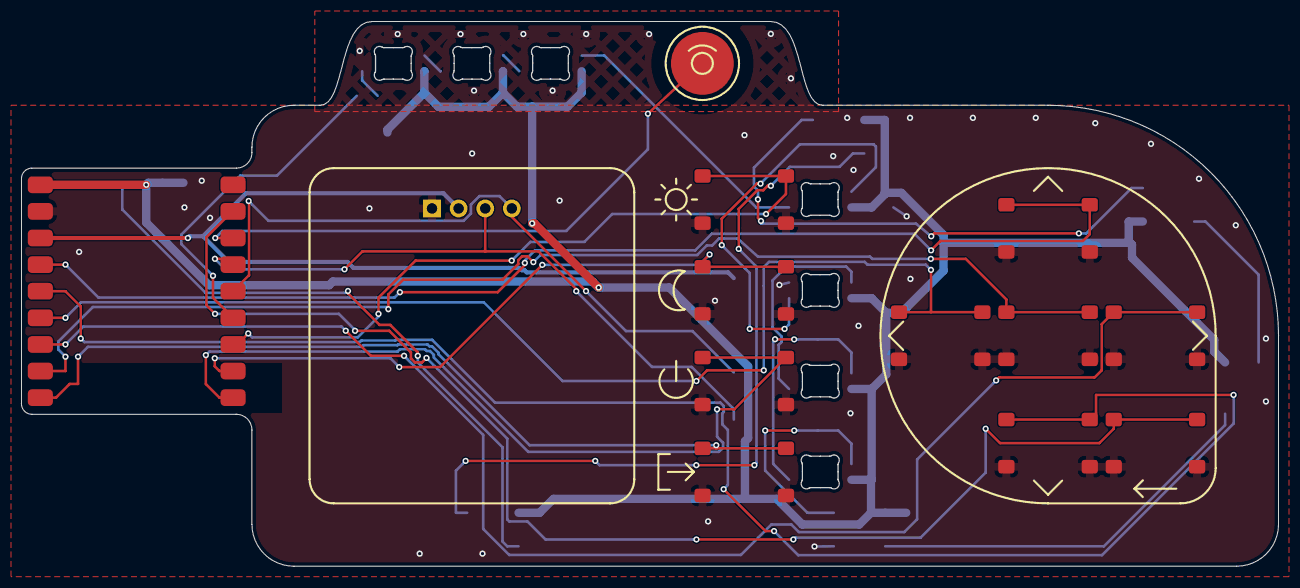
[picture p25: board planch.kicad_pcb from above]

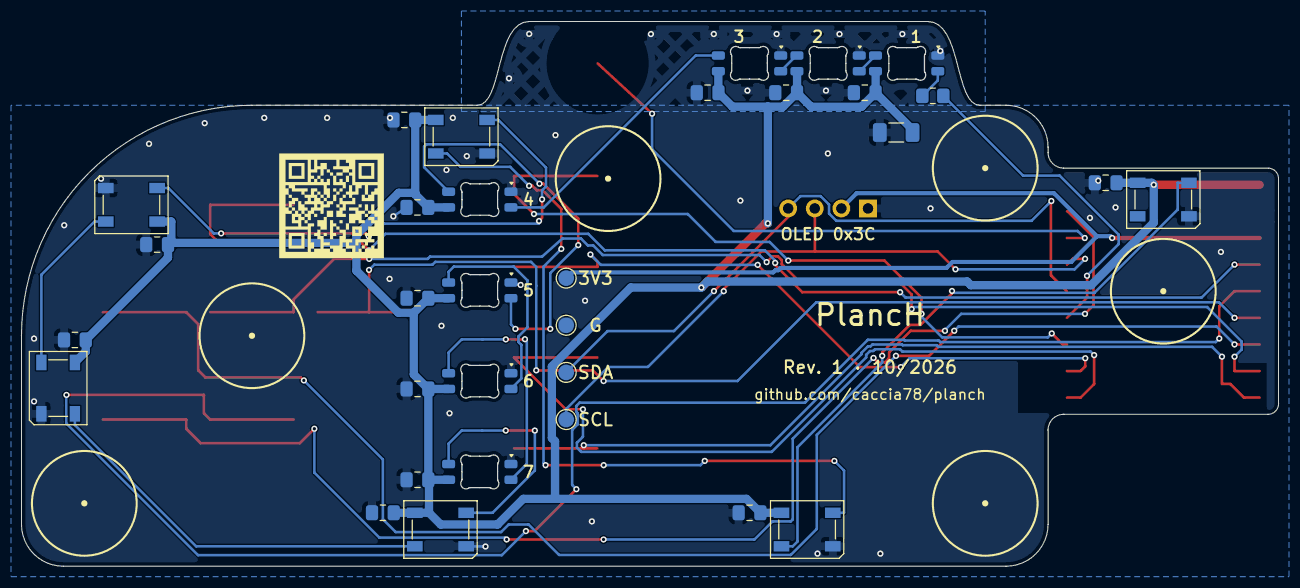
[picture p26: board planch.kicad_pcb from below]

Board: 2 copper layers, 120.0 x 52.0 mm, 45 parts (32 on the bottom side), 30 nets.

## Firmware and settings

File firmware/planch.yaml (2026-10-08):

# PlancH - ESPHome firmware for the board (Waveshare ESP32-S3-Zero).
# Menu built automatically by Home Assistant from the devices with the label "PlancH": logic in
# planch/core.yaml and planch/menu.h, Home Assistant package in homeassistant/planch.yaml.
# Wi-Fi is set after flashing: from web.esphome.io ("Configure Wi-Fi", Improv serial) or from the
# "PlancH" hotspot that the board opens while it has no network.

substitutions:
  led_pin: GPIO10

esphome:
  name: planch
  friendly_name: PlancH
  name_add_mac_suffix: true   # every panel gets its own name (planch-xxxxxx)
  project:
    name: "caccia78.planch"
    version: "1.0.0"

esp32:
  board: esp32-s3-devkitc-1
  framework:
    type: esp-idf

logger:
  hardware_uart: USB_SERIAL_JTAG   # frees TX/RX (Back button on GPIO 44)

ota:
  - platform: esphome
wifi:
  ap:
    ssid: "PlancH"
captive_portal:
improv_serial:

packages:
  core: !include planch/core.yaml

i2c:
  sda: GPIO11
  scl: GPIO12
  frequency: 400kHz

font:
  - file: "gfonts://Roboto"
    id: font_small
    size: 10
  - file: "gfonts://Roboto@500"
    id: font_title
    size: 10

# Title on the first row, then up to 4 rows: name on the left, state on the right,
# the selected row inverted
display:
  - platform: ssd1306_i2c
    model: "SSD1306 128x64"
    address: 0x3C
    id: oled
    update_interval: 100ms
    lambda: |-
      auto &m = planch::menu();
      if (!m.screen_on()) return;
      it.print(0, 0, id(font_title), m.title().c_str());
      it.line(0, 12, 127, 12);
      auto rows = m.rows();
      for (int i = 0; i < (int) rows.size(); i++) {
        int y = 14 + i * 12;
        bool sel = i == m.selected();
        if (sel) it.filled_rectangle(0, y, 128, 12);
        auto colour = sel ? COLOR_OFF : COLOR_ON;
        it.print(2, y, id(font_small), colour, rows[i].left.c_str());
        it.print(126, y, id(font_small), colour, TextAlign::TOP_RIGHT, rows[i].right.c_str());
      }

esp32_touch:
  setup_mode: true   # logs raw values to calibrate the threshold

# Keys to GND with internal pull-up; codes as planch::Key
binary_sensor:
  - platform: esp32_touch
    name: "Touch"
    pin: GPIO13
    threshold: 1000   # provisional value, calibrate after assembly
    on_press: [script.execute: { id: planch_key, code: 10 }]
  - platform: gpio
    name: "Up"
    pin: { number: GPIO1, inverted: true, mode: { input: true, pullup: true } }
    filters: [delayed_on: 10ms]
    on_press: [script.execute: { id: planch_key, code: 0 }]
  - platform: gpio
    name: "Down"
    pin: { number: GPIO2, inverted: true, mode: { input: true, pullup: true } }
    filters: [delayed_on: 10ms]
    on_press: [script.execute: { id: planch_key, code: 1 }]
  - platform: gpio
    name: "Left"
    pin:
      number: GPIO3        # strapping pin: used as input only
      inverted: true
      mode: { input: true, pullup: true }
      ignore_strapping_warning: true
    filters: [delayed_on: 10ms]
    on_press: [script.execute: { id: planch_key, code: 2 }]
  - platform: gpio
    name: "Right"
    pin: { number: GPIO4, inverted: true, mode: { input: true, pullup: true } }
    filters: [delayed_on: 10ms]
    on_press: [script.execute: { id: planch_key, code: 3 }]
  - platform: gpio
    name: "OK"
    pin: { number: GPIO5, inverted: true, mode: { input: true, pullup: true } }
    filters: [delayed_on: 10ms]
    on_press: [script.execute: { id: planch_key, code: 4 }]
  - platform: gpio
    name: "Back"
    pin: { number: GPIO44, inverted: true, mode: { input: true, pullup: true } }
    filters: [delayed_on: 10ms]
    on_press: [script.execute: { id: planch_key, code: 5 }]
  - platform: gpio
    name: "Scene 1"
    pin: { number: GPIO9, inverted: true, mode: { input: true, pullup: true } }
    filters: [delayed_on: 10ms]
    on_press: [script.execute: { id: planch_key, code: 6 }]
  - platform: gpio
    name: "Scene 2"
    pin: { number: GPIO8, inverted: true, mode: { input: true, pullup: true } }
    filters: [delayed_on: 10ms]
    on_press: [script.execute: { id: planch_key, code: 7 }]
  - platform: gpio
    name: "Scene 3"
    pin: { number: GPIO7, inverted: true, mode: { input: true, pullup: true } }
    filters: [delayed_on: 10ms]
    on_press: [script.execute: { id: planch_key, code: 8 }]
  - platform: gpio
    name: "Scene 4"
    pin: { number: GPIO6, inverted: true, mode: { input: true, pullup: true } }
    filters: [delayed_on: 10ms]
    on_press: [script.execute: { id: planch_key, code: 9 }]

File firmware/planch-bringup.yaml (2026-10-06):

# PlancH - assembly test firmware (bring-up). Every button, the touch area and the three LED groups
# are exposed to Home Assistant and on a web page at the module's IP address, to check each part
# while soldering. When the board is complete, flash planch.yaml (menu from Home Assistant).
# Wi-Fi is set after flashing: from web.esphome.io ("Configure Wi-Fi", Improv serial) or from the
# "PlancH" hotspot that the board opens while it has no network.

esphome:
  name: planch
  friendly_name: PlancH

esp32:
  board: esp32-s3-devkitc-1
  framework:
    type: esp-idf

logger:
  hardware_uart: USB_SERIAL_JTAG   # frees TX/RX (Back button on GPIO 44)

api:
ota:
  - platform: esphome
wifi:
  ap:
    ssid: "PlancH"
captive_portal:
improv_serial:

# Web page with LED groups and button states, for the tests during assembly
web_server:
  port: 80

i2c:
  sda: GPIO11
  scl: GPIO12
  frequency: 400kHz

font:
  - file: "gfonts://Roboto"
    id: font_small
    size: 10

display:
  - platform: ssd1306_i2c
    model: "SSD1306 128x64"
    address: 0x3C
    id: oled
    lambda: |-
      it.print(0, 0, id(font_small), "PlancH");

esp32_touch:
  setup_mode: true   # logs raw values to calibrate the threshold

binary_sensor:
  - platform: esp32_touch
    name: "Touch"
    pin: GPIO13
    threshold: 1000   # provisional value, calibrate after assembly

  # Buttons to GND with internal pull-up; debounce in firmware
  - platform: gpio
    name: "Up"
    pin: { number: GPIO1, inverted: true, mode: { input: true, pullup: true } }
    filters: [delayed_on: 10ms]
  - platform: gpio
    name: "Down"
    pin: { number: GPIO2, inverted: true, mode: { input: true, pullup: true } }
    filters: [delayed_on: 10ms]
  - platform: gpio
    name: "Left"
    pin:
      number: GPIO3        # strapping pin: used as input only
      inverted: true
      mode: { input: true, pullup: true }
      ignore_strapping_warning: true
    filters: [delayed_on: 10ms]
  - platform: gpio
    name: "Right"
    pin: { number: GPIO4, inverted: true, mode: { input: true, pullup: true } }
    filters: [delayed_on: 10ms]
  - platform: gpio
    name: "OK"
    pin: { number: GPIO5, inverted: true, mode: { input: true, pullup: true } }
    filters: [delayed_on: 10ms]
  - platform: gpio
    name: "Scene 4"
    pin: { number: GPIO6, inverted: true, mode: { input: true, pullup: true } }
    filters: [delayed_on: 10ms]
  - platform: gpio
    name: "Scene 3"
    pin: { number: GPIO7, inverted: true, mode: { input: true, pullup: true } }
    filters: [delayed_on: 10ms]
  - platform: gpio
    name: "Scene 2"
    pin: { number: GPIO8, inverted: true, mode: { input: true, pullup: true } }
    filters: [delayed_on: 10ms]
  - platform: gpio
    name: "Scene 1"
    pin: { number: GPIO9, inverted: true, mode: { input: true, pullup: true } }
    filters: [delayed_on: 10ms]
  - platform: gpio
    name: "Back"
    pin: { number: GPIO44, inverted: true, mode: { input: true, pullup: true } }
    filters: [delayed_on: 10ms]

light:
  - platform: esp32_rmt_led_strip
    id: led_chain
    pin: GPIO10
    num_leds: 13
    chipset: SK6812
    channel_colors: GRB
    internal: true
    color_correct: [40%, 40%, 40%]   # limits total current
  - platform: partition
    name: "Status LEDs"        # D1-D3, on the ear
    segments:
      - id: led_chain
        from: 0
        to: 2
  - platform: partition
    name: "Scene LEDs"         # D4-D7
    segments:
      - id: led_chain
        from: 3
        to: 6
  - platform: partition
    name: "Backlight"          # D8-D13
    segments:
      - id: led_chain
        from: 7
        to: 12

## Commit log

2026-10-06 Added 3D interactive viewer for the board
    [planch-B_Cu.gbl, planch-B_Mask.gbs, planch-B_Paste.gbp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]
2026-10-06 Release 1.0: add 3D viewers for PCB and desk stand
    - Added model-viewer component to both PCB and desk stand documentation
    - Generated GLB models for interactive 3D visualization
    - Configured global model-viewer script loading in MkDocs
    - Removed standalone HTML viewer (no longer needed)
    Generated by: python tools/rilascio.py --versione 1.0
2026-10-06 Desk stand 3D viewer: button to show the board in the stand
    The stand model is now Y-up with a material (it was lying on its back); the new
    assembly model places the KiCad board on its feet inside the stand.
    Claude-Session: https://claude.ai/code/session_0156ANrBqXzEKEnVDQi1aLuT
2026-10-06 Desk stand 3D viewer: switch on the LEDs, with a colour picker
    The LEDs have their own materials per group, and the light slots of the stand glow with
    the backlight (model-viewer has no lights that shine onto the desk).
    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
2026-10-06 3D viewers: LED groups with bloom on the desk stand, opaque board
    - Status, scene and backlight LEDs switch on separately, with a glow (model-viewer-effects).
    - model-viewer 4.1.0 loaded as an ES module with three.js 0.172, only on the two viewer
    pages (it used to load on every page).
    - In the stand assembly the solder mask and board body are opaque, as on the real board.
    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
2026-10-06 Board 3D viewer: LED groups with glow, opaque black board
    The board model has the same LED controls as the desk stand, and the solder mask is
    opaque as on the real board. leggio.py writes the viewer models only with --viewer, so
    the documented command works again without trimesh.
    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
2026-10-06 Wall mount: magnetic ring bracket and wall base
    A ring bracket glued behind the board and a base stuck to the wall with removable
    strips, held together by six 5 x 3 mm magnets and two centring cones. Both follow the
    board outline 9.5 mm in, so the backlight shines on the wall around them.
    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
    [planch-wall-base.3mf, planch-wall-base.step, planch-wall-base.stl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]
2026-10-06 Docs: wall mount page with 3D viewer
    Parts list, printing, assembly (magnet polarity) and design data, with a 3D viewer of
    the parts on the wall and of the board hanging on them, LEDs and the backlight glowing on
    the wall.
    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
2026-10-06 Firmware: menu built automatically from Home Assistant
    - Choose the devices with the label "PlancH" and the scene keys with "PlancH S1"-"S4":
    the panel groups them by room and type. Package homeassistant/planch.yaml.
    - LEDs: D1 shows problems, D2-D3 and the backlight are lights for your automations, the
    scene LEDs show the active scene and confirm each press.
    - Wi-Fi set after flashing, no secrets file. Assembly test firmware planch-bringup.yaml,
    test bench planch-test.yaml with its dashboard.
    - Docs: Firmware and Home Assistant pages rewritten, assembly guide updated.
    Claude-Session: https://claude.ai/code/session_0156ANrBqXzEKE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
    [menu.h, planch-bringup.yaml, planch.yaml]
2026-10-06 Install the firmware from the browser (ESP Web Tools)
    The documentation workflow builds the firmware with esphome/build-action (PlancH for the
    ESP32-S3, the test bench for a classic ESP32), writes the ESP Web Tools manifest and
    publishes it with the site. Install button on the Firmware page.
    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
2026-10-06 Video: real firmware menu and the wall mount
    31 s: on the desk stand the display shows the firmware menu and a scene key confirms in
    green; then the board snaps onto the wall mount and the backlight lights up the wall.
    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
2026-10-06 Video: title, feature callouts, closing card and sound
    42 s with a title, callouts pointing to the board features, a closing card and a
    soundtrack: "Chill Out Theme" by Komiku (CC0) plus sound effects synced to the action.
    Music credit in LICENSE.md.
    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
2026-10-07 Video: front-facing board, accessory titles and callouts
    - The board turns to face the camera for the front and back callouts,
    which stay on screen longer
    - The desk stand and the wall mount each pause with a title and three
    callouts before the board is placed
    - The camera rises over the desk stand so the menu on the display is
    readable
    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
2026-10-08 Colour lights, test bench page and card, separate installers
    - Colour lights: Brightness, Colour (editable palette), White and Effect rows; Up/Down
    scroll on to the next light. The menu follows label and area changes by itself.
    - New page "Try it without the hardware": the test bench on a classic ESP32 with its own
    installer, and the Home Assistant card planch-card that draws the panel.
    - The Firmware page installer now installs only PlancH (ESP32-S3).
    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
2026-10-08 More than one PlancH per home, switches in the menu
    - Label "PlancH" for devices on every panel, "PlancH <name>" for one panel; the name is set
    in the "Panel" field on the device page, no new firmware needed. Scene keys per panel.
    - Switches (smart plugs) under "Switches".
    - Panels installed from the browser get a unique name (planch-xxxxxx).
    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
2026-10-12 Adopt PlancH in the ESPHome Device Builder; usage examples
    - The menu model is now an ESPHome external component (firmware/components/planch/)
    - dashboard_import: adopted panels and test benches load firmware/planch/import*.yaml from GitHub
    - Touch sensor id touch_key, to set the threshold on an adopted panel
    - New page: Usage examples (office, bedside, kitchen timer, indicators)
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2026-10-16 Board Wi-Fi: power saving off, transmit power 8.5 dB
    With the defaults the first assembled board kept dropping off the network
    (API reachable about 1 time in 3, OTA stopped halfway); with these two
    settings it is stable. Firmware page: install over USB when the wireless
    install stops.
    Claude-Session: https://claude.ai/code/session_01TY6w4GAHF1t7eiK9bxe5r1
2026-10-17 Touch area: 0.25 ms measurement and threshold 2500
    With the ESPHome default (8 ms) the ESP32-S3 touch counter was stuck at its
    top value, 4194303. With 0.25 ms the first board reads about 10 500 at rest
    and 15 000-28 000 with a finger; threshold 2500 (rise over the resting
    value) tested with no false touches. Setup mode off in the board firmware.
    Firmware and assembly pages: how to pick the threshold on the S3.
    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
2026-10-17 Display: 11 px text, long names shortened with "…"
    Title in the top 16 px (the yellow band of two-colour OLEDs), 4 rows of
    12 px below with Roboto 11; the state on the right takes up to half the row
    and the name is shortened with "…". Tested on the first board. Same layout
    in planch-card 1.2.
    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
2026-10-17 Touch threshold 40 000: false touches kept the display on
    Measured on the first board: about 110 000 at rest, jumping by about 3 700
    between two levels, 210 000-280 000 with a finger. The old threshold, 2500,
    came from values read ten times too small. Numbers fixed in the docs too.
2026-10-17 Room climate: temperature in the room list, temperature and humidity next to the title
    Labelled temperature and humidity sensors of each room (on the sensor, or on a device with
    sensors only); planch-card 1.3.
    Claude-Session: https://claude.ai/code/session_016AvtUmqwZ8vCTzqV5vCtzN
2026-10-17 Room climate: temperature also from sensors in °C or °F without a device class (MQTT); D1 red only without Home Assistant (log viewers do not count); backlight off and scene LED brightness settings
    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
2026-10-20 Clock on Scene 4 with today's forecast, backlight and settings kept after a power cut, desk stand seventh support
